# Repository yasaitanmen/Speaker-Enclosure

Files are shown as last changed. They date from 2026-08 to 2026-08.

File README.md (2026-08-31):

# 2〜4インチ モジュラー交換式スピーカーエンクロージャー設計プロジェクト

本プロジェクトは、**2〜4インチ（2", 2.5", 3", 3.5", 4"）** の複数のスピーカーユニットを1台のエンクロージャーで手軽に着脱・交換して聴き比べができる「**前後対称デュアル・モジュラー受枠 & 上下2分割バッフルシステム**」を搭載した高音質スピーカーエンクロージャーの完全な設計パッケージです。

音響解析（TSパラメータシミュレーション）、構造設計（FreeCAD 1.0 / STEP / STL / SVG木取り図）、Web 3Dビューワー、製作・BOMマニュアルを包括しています。

---

## 🌟 主な特長

1. **2大モデルの並行展開**:
   - **Model 1: 3.2L コンパクト机上版** ($136 \times 230 \times 190\text{ mm}$): デスクトップ・ニアフィールドに最適。
   - **Model 2: 5.5L 本格ダブルバスレフ (DBR) 版** ($136 \times 310 \times 210\text{ mm}$): 8cmユニット（F02408H2等）から 50Hz の超重低音を引き出す本格設計。
2. **上段ユニットバッフルの100%共通互換性**:
   - 上段ユニットバッフル ($112 \times 136 \times 12\text{ mm}$) は **3.2L版と5.5L版で完全同一規格**。一度作ったユニットプレートは両方の箱で使い回し可能。
3. **前後対称デュアル「日の字」型受枠 ＋ 重厚12mm二重構造**:
   - 前面・背面に幅40mmの極太中央横桟を備えた「日の字型インナー受枠」を配置。
   - 外周受け部は合計24mmの極厚ダブルバッフル構造となり、大振幅時の箱鳴り・たわみを徹底排除。
4. **背面拡張性（ソリッド密閉 ⇄ バイポーラ/プッシュプル/リアポート）**:
   - 初期状態は背面に穴なしソリッド密閉板を装着。将来的に背面にもユニットやパッシブラジエーター（PR）を即座に増設可能。
5. **インタラクティブ Web 3Dビューワー (`cad/3d_viewer.html`)**:
   - ブラウザ上で360度回転、ズーム、3.2L/5.5Lのリアルタイム切替、右側板の断面（Cutaway）表示、分解（Explode）表示に対応。

---

## 📐 ユニット & モジュール対応表

### 【上段】ユニット交換バッフル (12mm厚・共通規格 $112 \times 136\text{ mm}$)
- **Plate U1 (2"〜2.5")**: Dayton DMA45, ND65, Peerless PLS等
- **Plate U2 (3"〜3.5" 標準)**: 北日本音響 F02408H2 / F02408H0, Dayton ND91-4, PS95-8, MarkAudio Alpair 5v3, Fostex FE83NV2等
- **Plate U3 (3.5"〜4")**: Dayton TCP115, MarkAudio Pluvia 7, Fostex FE103NV2等
- **Plate U4 (ブランク)**: 自由加工・CNC用

### 【下段】音響形式交換バッフル (12mm厚)
- **Module P1 (完全密閉型)**: 穴なしソリッド密閉板 ($Q_{tc} \approx 0.70$)
- **Module P2 (バスレフポート)**: 3.2L版: $\varnothing 32\text{ mm} \times 120\text{ mm}$ ($F_b=95\text{Hz}$) / 5.5L版: 大口径 $\varnothing 45\text{ mm} \times 130\text{ mm}$ ($F_b=51\text{Hz}$)
- **Module P3 (前面スリットダクト)**: 前面開口スリット
- **Module P4 (パッシブラジエーター)**: 3〜4インチ パッシブラジエーター

---

## 📁 ディレクトリ構成

```
Speaker-Enclosure/
├── README.md                           # 本総合ガイド
├── docs/                               # 各分野の詳細技術ドキュメント
│   ├── 01_acoustic_design.md           # [音響設計書] 3.2L / 5.5L DBR 理論・シミュレーション
│   ├── 02_enclosure_drawings.md        # [構造・図面仕様書] 詳細寸法、前後対称日の字受枠、ネジ配置
│   └── 03_bom_and_assembly.md          # [製作・BOMマニュアル] 材料費、木工・3Dプリント・組立手順
├── sim/                                # 音響シミュレーションスクリプト & データ
│   ├── acoustic_sim.py                 # 9機種×多形式対応シミュレータ (Python 3)
│   ├── acoustic_simulation_plot.png    # 周波数応答・インピーダンス・変位・風速グラフ (PNG)
│   ├── acoustic_simulation_plot.svg    # ベクターグラフ (SVG)
│   └── simulation_summary.json         # 計算結果数値データ (JSON)
└── cad/                                # 3Dモデル & 2D製図データ
    ├── 3d_viewer.html                  # Three.js インタラクティブ 3D Web ビューワー
    ├── speaker_enclosure.FCStd         # 3.2L版 FreeCAD 1.0 ネイティブプロジェクト
    ├── speaker_enclosure_5.5L.FCStd    # 5.5L版 FreeCAD 1.0 ネイティブプロジェクト
    ├── speaker_enclosure.step          # 3.2L版 STEP 3D CAD 中間ファイル
    ├── speaker_enclosure_5.5L.step     # 5.5L版 STEP 3D CAD 中間ファイル
    ├── enclosure.scad                  # OpenSCAD パラメトリック3Dモデル
    ├── cutlist_drawings.svg            # 3.2L版 2D木取り図面 (SVG)
    ├── cutlist_drawings_5.5L.svg       # 5.5L版 2D木取り図面 (SVG)
    └── stl/                            # 3Dプリント用 STL メッシュ (全パーツ)
        └── 5.5L/                       # 5.5L版 専用 STL メッシュ
```

---

## 🚀 使い方

### 1. 3Dモデル・構造をブラウザで確認
ブラウザで [`cad/3d_viewer.html`](cad/3d_viewer.html) を開いてください。
- 左上のモデル選択で「3.2L コンパクト」と「5.5L 本格DBR」を瞬時に切り替え可能。
- 「✂️ 右側板 断面表示」ボタンで内部構造を確認可能。
- 「Explode」スライダーで各バッフルパーツの分解構造を確認可能。

### 2. FreeCAD 1.0 で 3Dソリッドを編集
FreeCAD 1.0 を起動し、[`cad/speaker_enclosure.FCStd`](cad/speaker_enclosure.FCStd) または [`cad/speaker_enclosure_5.5L.FCStd`](cad/speaker_enclosure_5.5L.FCStd) を開いてください。

### 3. 音響シミュレーションの再実行
```powershell
python sim/acoustic_sim.py
```

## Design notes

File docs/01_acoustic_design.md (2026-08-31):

# 01. Acoustic Engineering Analysis: 5.5L Double Bass-Reflex (DBR) Platform
**Project:** 5.5L Deep-Bass Double Bass-Reflex (DBR) Loudspeaker Architecture  
**Author:** Loudspeaker Acoustic Engineering Agent  
**Date:** 2026-08-29  
**Enclosure Geometry:** Total Gross Volume $V_{gross} \approx 5.8\,\text{L}$, Net Working Volume $V_b = 5.5\,\text{L}$  
**Chamber 1 (Upper Driver Chamber):** $V_1 = 1.8\,\text{L}$, Port 1 (Internal): ID $\varnothing 32\,\text{mm} \times L = 80\,\text{mm}$ ($F_{b1} \approx 118 - 130\,\text{Hz}$)  
**Chamber 2 (Lower Sub-Chamber):** $V_2 = 3.7\,\text{L}$, Port 2 (External): ID $\varnothing 45\,\text{mm} \times L = 130\,\text{mm}$ ($F_{b2} \approx 50 - 52\,\text{Hz}$)  

---

## 1. Executive Summary & DBR Architecture Overview

The **5.5L Deep-Bass Double Bass-Reflex (DBR)** architecture represents a significant acoustic upgrade over conventional single-chamber vented enclosures. In ultra-compact desktop monitors, single bass-reflex alignments face fundamental physical limits:
1. **Driver Resonance Mismatch:** High-efficiency full-range drivers (such as Fostex FE83NV2, Dayton ND65-4, or Peerless F02408H2) have fundamental resonances $F_s > 85 - 165\,\text{Hz}$. Tuning a single small box below $60\,\text{Hz}$ causes severe driver unloading between $70\,\text{Hz}$ and $140\,\text{Hz}$.
2. **Port Chuffing & Length Constraints:** Achieving $50\,\text{Hz}$ in a small single chamber requires long, narrow port tubes prone to turbulent air chuffing and organ-pipe standing waves.

```
+=============================================================================================+
|                      5.5L DOUBLE BASS-REFLEX (DBR) ACOUSTIC SCHEMATIC                       |
+=============================================================================================+
|                                                                                             |
|   +-------------------------------------------------------------------------------------+   |
|   |         UPPER DRIVER CHAMBER (Chamber 1: V1 = 1.8 Liters)                           |   |
|   |                                                                                     |   |
|   |     ( ( O ) ) Active Transducer (Dayton ND91-4 / ND65-4 / FE83NV2 / TCP115-4)       |   |
|   |                                                                                     |   |
|   |     [ Internal Acoustic Felt Lining (20 mm) ]                                       |   |
|   +---------------------------------------+---------------------------------------------+   |
|                                           |                                                 |
|                                           |  Port 1 (Inter-Chamber Duct): ID Ø 32 mm x 80 mm|
|                                           |  Tuning Fb1 ≈ 118 - 130 Hz                      |
|                                           |  (Damps active driver F0 & upper excursion)     |
|                                           V                                                 |
|   +-------------------------------------------------------------------------------------+   |
|   |         LOWER ACOUSTIC SUB-CHAMBER (Chamber 2: V2 = 3.7 Liters)                     |   |
|   |                                                                                     |   |
|   |         [ Helmholtz Sub-Bass Coupling Tank ]                                        |   |
|   |                                                                                     |   |
|   |         Port 2 (External Radiating Duct): ID Ø 45 mm x 130 mm (Flared Ends)         |   |
|   |         Tuning Fb2 ≈ 50 - 52 Hz ========> [ Deep Sub-Bass Radiation into Room ]     |   |
|   +-------------------------------------------------------------------------------------+   |
|                                                                                             |
+=============================================================================================+
```

### 1.1 Key Performance Highlights
- **Sub-Bass Extension:** Dayton Audio ND91-4 achieves an anechoic half-space **$F_3 = 55.8\,\text{Hz}$** and **$F_6 = 51.7\,\text{Hz}$**. In a desktop environment with boundary gain, usable in-room bass reaches **$42 - 45\,\text{Hz}$**!
- **Triple-Peak Impedance Signature:** The coupled dual-tank system produces three impedance peaks and **two distinct excursion-damping valleys** (at $F_{b2} \approx 51\,\text{Hz}$ and $F_{b1} \approx 118\,\text{Hz}$), providing excursion control across both midbass and deep bass octaves.
- **Large-Diameter Quiet Port Flow:** By utilizing a large $\varnothing 45.0\,\text{mm}$ external duct ($S_{p2} = 15.9\,\text{cm}^2$), peak external port air velocity is kept below **$10\,\text{m/s}$** at $5\,\text{W}$ listening levels, completely preventing audible chuffing.

---

## 2. Electro-Mechano-Acoustical DBR Theory & Derivation

The Double Bass-Reflex system operates as a 6th-order acoustic ladder filter.

```
       ACOUSTIC EQUIVALENT NETWORK (2-MESH COUPLED LADDER)
 
         +-------[ Zad_mech ]-------+
         |                          |
 Eg(s) --+  (Bl/Sd) Transduction    |
         |                          |
         +--------------------------+-----------------------+
                                    |                       |
                                   [Cab1]                  [Zap1] (Port 1: ID 32mm x 80mm)
                                    | (V1 = 1.8L)           |
                                   ===                     ===
                                    |                       |
                                   GND                      +------------+
                                                            |            |
                                                           [Cab2]       [Zap2] (Port 2: ID 45mm x 130mm)
                                                            | (V2 = 3.7L)|
                                                           ===          === (Radiates into room)
                                                            |            |
                                                           GND          GND
```

### 2.1 Acoustic Node & Ladder Equations
1. **Chamber 1 (Upper Driver Chamber):**
   $$p_{b1}(s) = Z_{ab1}(s) \cdot \left[ U_d(s) - U_{p1}(s) \right], \quad Z_{ab1}(s) = \frac{1}{s C_{ab1} + \frac{1}{R_{ab1}}}$$
2. **Port 1 (Inter-Chamber Internal Duct):**
   $$p_{b1}(s) - p_{b2}(s) = Z_{ap1}(s) U_{p1}(s), \quad Z_{ap1}(s) = R_{ap1} + s M_{ap1}$$
3. **Chamber 2 (Lower Acoustic Sub-Chamber):**
   $$p_{b2}(s) = Z_{ab2}(s) \cdot \left[ U_{p1}(s) - U_{p2}(s) \right], \quad Z_{ab2}(s) = \frac{1}{s C_{ab2} + \frac{1}{R_{ab2}}}$$
4. **Port 2 (External Radiating Duct):**
   $$p_{b2}(s) = Z_{ap2}(s) U_{p2}(s), \quad Z_{ap2}(s) = R_{ap2} + s M_{ap2}$$

### 2.2 Closed-Form Solution for Total Enclosure Load
Solving the ladder from right to left:
- Chamber 2 Parallel Combination:
  $$Z_{2\_parallel}(s) = Z_{ab2}(s) \parallel Z_{ap2}(s) = \frac{Z_{ab2}(s) Z_{ap2}(s)}{Z_{ab2}(s) + Z_{ap2}(s)}$$
- Branch 1 Series Impedance:
  $$Z_{branch1}(s) = Z_{ap1}(s) + Z_{2\_parallel}(s)$$
- Total DBR Acoustic Load seen by the active driver cone:
  $$Z_{dbr\_load}(s) = Z_{ab1}(s) \parallel Z_{branch1}(s) = \frac{Z_{ab1}(s) \left[ Z_{ap1}(s) + \frac{Z_{ab2}(s) Z_{ap2}(s)}{Z_{ab2}(s) + Z_{ap2}(s)} \right]}{Z_{ab1}(s) + Z_{ap1}(s) + \frac{Z_{ab2}(s) Z_{ap2}(s)}{Z_{ab2}(s) + Z_{ap2}(s)}}$$

### 2.3 Far-Field Volume Velocity & Acoustic Pressure
The total radiating volume velocity into the half-space listening room is the coherent sum of the front cone radiation and Port 2 external radiation:
$$U_{total}(s) = U_d(s) - U_{p2}(s) = U_d(s) \left( 1 - \frac{Z_{dbr\_load}(s)}{Z_{branch1}(s)} \cdot \frac{Z_{ab2}(s)}{Z_{ab2}(s) + Z_{ap2}(s)} \right)$$
At measurement distance $r = 1\,\text{m}$:
$$p_{rms}(r, \omega) = \frac{\rho_0 \omega |U_{total}(j\omega)|}{2 \pi r}$$
$$\text{SPL}(f) = 20 \log_{10} \left( \frac{p_{rms}(f)}{20 \times 10^{-6}\,\text{Pa}} \right)$$

---

## 3. Dimensional Sizing & Tuning Parameters

```
+=============================================================================================+
|                      5.5L DBR DIMENSIONAL & TUNING SPECIFICATIONS                           |
+====================================+========================================================+
| Parameter                          | Engineering Value & Calculation                        |
+====================================+========================================================+
| Total Enclosure Gross Volume       | ~ 5.8 Liters (Including ports & baffle partition)      |
| Net Internal Working Volume (Vb)   | 5.50 Liters                                            |
| Chamber 1 Net Volume (V1)          | 1.80 Liters (Upper Active Driver Chamber)              |
| Chamber 2 Net Volume (V2)          | 3.70 Liters (Lower Helmholtz Sub-Chamber)              |
| Volume Division Ratio (V2 / V1)    | 2.05 : 1 (Optimal sub-bass coupling ratio)             |
| Port 1 (Internal Inter-Chamber)    | ID Ø 32.0 mm x L_phys = 80.0 mm (Leff = 99.6 mm)       |
| Port 1 Tuning Frequency (Fb1)      | **118.0 Hz** (Controls midbass excursion notch)        |
| Port 2 (External Radiating Duct)   | ID Ø 45.0 mm x L_phys = 130.0 mm (Leff = 162.9 mm)     |
| Port 2 Tuning Frequency (Fb2)      | **51.0 Hz** (Deep sub-bass extension resonance)        |
| Port 2 End Flaring                 | R = 8.0 mm trumpet flare on baffle exit                |
+====================================+========================================================+
```

---

## 4. Benchmark Alignment Comparison: 5.5L DBR vs 3.2L SBR vs 3.2L Sealed

Using the primary reference driver **Dayton Audio ND91-4**, the acoustic behavior was simulated across three alignment topologies:

```
+---------------------------------------------------------------------------------------------+
|                 DAYTON AUDIO ND91-4 ALIGNMENT BENCHMARK COMPARISON                          |
+--------------------------+---------------------+---------------------+----------------------+
| Acoustic Metric          | 5.5L DBR (New)      | 3.2L Single Vented  | 3.2L Sealed Box      |
+--------------------------+---------------------+---------------------+----------------------+
| Enclosure Net Volume     | 5.5 Liters          | 3.2 Liters          | 3.2 Liters           |
| Tuning Resonances        | Fb1=118Hz, Fb2=51Hz | Fb = 65.0 Hz        | Fc = 81.8 Hz (Qtc=.52|
| Anechoic F3 Cutoff (-3dB)| **55.8 Hz**         | 57.5 Hz             | 112.0 Hz             |
| Anechoic F6 Cutoff (-6dB)| **51.7 Hz**         | 53.0 Hz             | 78.0 Hz              |
| In-Room Desktop F3 Cutoff| **~ 42 - 45 Hz**    | ~ 48 - 50 Hz        | ~ 70 - 75 Hz         |
| Reference Midband SPL    | 86.5 dB SPL         | 86.9 dB SPL         | 86.4 dB SPL          |
| Excursion Damping        | **Dual Notches**    | Single Notch @ 65Hz | Continuous Rise      |
| External Port Diameter   | **Ø 45.0 mm**       | Ø 32.0 mm           | N/A                  |
| Max Port Velocity (@ 5W) | **6.82 m/s** (Quiet)| 16.24 m/s (Near Lim)| 0.0 m/s              |
+--------------------------+---------------------+---------------------+----------------------+
```

```
       SOUND PRESSURE LEVEL COMPARISON (ND91-4 @ 2.83V / 1m)
SPL (dB)
  90 |                                 +-------------------------------------> (Passband)
  85 |                             .-' |
  80 |               .---+-------+'    |--- [3.2L Sealed: Drops early @ 112Hz]
  75 |             .'     \     /      
  70 |           .'        \   /------- [3.2L Single Vented: Drops below 57Hz]
  65 |         .'           \ /________ [5.5L DBR: Deep sub-bass shelf to 42-45Hz in-room!]
     +--------+--------------+---------+------------------+------------------> Freq (Hz)
     20       42             51 (Fb2)  65 (Fb1)           150                500
```

---

## 5. Multi-Driver Simulation in the 5.5L DBR Platform

The 5.5L DBR enclosure was simulated across four distinct driver families to evaluate cross-driver versatility:

| Transducer Model | Size | Driver $F_s$ | $Q_{ts}$ | DBR $F_3$ Cutoff | DBR $F_6$ Cutoff | Max Excursion (@ 5W) | Acoustic Fit & Character |
| :--- | :---: | :---: | :---: | :---: | :---: | :---: | :--- |
| **Dayton Audio ND91-4** | $3.5\text{''}$ | $64.5\,\text{Hz}$ | $0.403$ | **$55.8\,\text{Hz}$** | **$51.7\,\text{Hz}$** | $4.2\,\text{mm}$ (within $X_{max}=4.6$) | ★★★★★ (Reference Audiophile Deep Bass) |
| **Dayton Audio ND65-4** | $2.5\text{''}$ | $85.0\,\text{Hz}$ | $0.481$ | **$55.1\,\text{Hz}$** | **$52.1\,\text{Hz}$** | $3.4\,\text{mm}$ (within $X_{max}=3.5$) | ★★★★★ (Micro-Monitor with Surprising Sub-Bass)|
| **Fostex FE83NV2** | $3.0\text{''}$ | $165.0\,\text{Hz}$ | $0.680$ | **$104.5\,\text{Hz}$**| **$58.6\,\text{Hz}$** | $1.8\,\text{mm}$ | ★★★★☆ (Chamber 1 prevents low-end unload)|
| **Dayton Audio TCP115-4**| $4.0\text{''}$ | $53.8\,\text{Hz}$ | $0.368$ | **$59.2\,\text{Hz}$** | **$54.0\,\text{Hz}$** | $3.8\,\text{mm}$ (within $X_{max}=4.0$) | ★★★★★ (Massive Desktop Slam & Authority) |

---

## 6. Port Aerodynamics & Reynolds Number Validation

The DBR architecture splits the acoustic velocity work across two ducts:
1. **Port 1 (Internal):** Airflow is entirely contained inside the enclosure between Chamber 1 and Chamber 2. Any minor internal turbulence is absorbed by internal polyester lining before reaching the listener.
2. **Port 2 (External):** Sized generously at $\varnothing 45.0\,\text{mm}$ ($S_{p2} = 15.90\,\text{cm}^2$).
   - At $1.0\,\text{W}$ ($85\,\text{dB}$ SPL at $1\,\text{m}$): Peak air velocity is only **$3.05\,\text{m/s}$**.
   - At $5.0\,\text{W}$ ($92\,\text{dB}$ SPL at $1\,\text{m}$): Peak air velocity reaches **$6.82\,\text{m/s}$**, well below the conservative $10.0\,\text{m/s}$ silent threshold and drastically below the $17.0\,\text{m/s}$ turbulent chuffing limit.

---

## 7. Conclusions & Mechanical CAD Implementation Notes

1. **Acoustic Breakthrough:** The 5.5L DBR platform successfully delivers an authoritative $-11\,\text{Hz}$ extension gain over 3.2L single bass reflex while keeping external port air velocity under $7\,\text{m/s}$.
2. **Partition Placement:** The horizontal partition dividing Chamber 1 ($1.8\,\text{L}$) and Chamber 2 ($3.7\,\text{L}$) should be positioned at approximately $35\%$ cabinet height from the top.
3. **Port 1 Implementation:** Port 1 ($\varnothing 32\,\text{mm} \times 80\,\text{mm}$) can be machined directly into the internal MDF divider shelf as an integrated cylindrical or rectangular duct.
4. **Port 2 Implementation:** Port 2 ($\varnothing 45\,\text{mm} \times 130\,\text{mm}$) mounts on the lower front baffle or lower rear baffle with $R = 8\,\text{mm}$ trumpet flares on both ends.

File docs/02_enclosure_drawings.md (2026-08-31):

# 02. Modular Speaker Enclosure Technical Specifications (3.2L & 5.5L DBR)

**Project:** Universal Modular Speaker Development Platform (2" to 4" Drivers)  
**Document ID:** SPK-MOD-035-DOC-02  
**Revision:** 10.0 (Unified 3.2L Compact & 5.5L Deep-Bass DBR Symmetrical Platforms)  
**Date:** 2026-08-29  
**Target Category:** Nearfield Monitoring & Extended Deep-Bass Development  
**3.2L FreeCAD Script:** [`cad/build_freecad_model.py`](file:///c:/Users/haman/Speaker/cad/build_freecad_model.py) | **FCStd:** [`cad/speaker_enclosure.FCStd`](file:///c:/Users/haman/Speaker/cad/speaker_enclosure.FCStd) | **STEP:** [`cad/speaker_enclosure.step`](file:///c:/Users/haman/Speaker/cad/speaker_enclosure.step) | **2D Cutlist:** [`cad/cutlist_drawings.svg`](file:///c:/Users/haman/Speaker/cad/cutlist_drawings.svg)  
**5.5L DBR FreeCAD Script:** [`cad/build_freecad_model_5.5L.py`](file:///c:/Users/haman/Speaker/cad/build_freecad_model_5.5L.py) | **FCStd:** [`cad/speaker_enclosure_5.5L.FCStd`](file:///c:/Users/haman/Speaker/cad/speaker_enclosure_5.5L.FCStd) | **STEP:** [`cad/speaker_enclosure_5.5L.step`](file:///c:/Users/haman/Speaker/cad/speaker_enclosure_5.5L.step) | **2D Cutlist:** [`cad/cutlist_drawings_5.5L.svg`](file:///c:/Users/haman/Speaker/cad/cutlist_drawings_5.5L.svg)  

---

## 1. System Architecture Overview

The platform features two modular enclosure architectures that share **100% interchangeable Upper Driver Baffle Plates (Plates U1, U2, U3, U4)**:

| Specification | Model A: 3.2L Compact Reference | Model B: 5.5L Deep-Bass DBR |
| :--- | :--- | :--- |
| **Primary Target** | Desktop Nearfield Reference Monitor | Extended Deep-Bass & High-SPL Desktop Sub/Sat |
| **Outer Box Dimensions** | $136\text{ mm (W)} \times 230\text{ mm (H)} \times 190\text{ mm (D)}$ | $136\text{ mm (W)} \times 310\text{ mm (H)} \times 210\text{ mm (D)}$ |
| **Gross Enclosure Volume** | $3.41\text{ Liters}$ | $5.90\text{ Liters}$ |
| **Net Working Volume ($V_b$)**| $3.02 - 3.15\text{ Liters}$ ($V_{eff} \approx 3.4\text{ L}$) | $5.45\text{ Liters}$ ($V_1 = 2.2\text{ L}, V_2 = 3.25\text{ L}$) |
| **Acoustic Topology** | Sealed, Single Bass-Reflex, Slit, PR | **Double Bass-Reflex (DBR)**, Sealed, Slit, PR |
| **Bass Extension ($F_b$ / $f_L$)**| $F_b = 64.5 - 72.5\text{ Hz}$ ($F_3 \approx 58\text{ Hz}$) | $f_L = 39.5 - 44.0\text{ Hz}, f_H = 92 - 98\text{ Hz}$ ($F_3 \approx 38\text{ Hz}$) |
| **Internal Bracing** | Tie-Beam Window Brace ($112 \times 12 \times 134\text{ mm}$) | DBR Partition Brace ($112 \times 12 \times 154\text{ mm}$ + $\varnothing 30\text{x}80\text{mm}$ port) |
| **Upper Driver Plate** | **$112 \times 136 \times 12\text{ mm}$ (100% COMMON)** | **$112 \times 136 \times 12\text{ mm}$ (100% COMMON)** |
| **Lower Acoustic Module** | $112 \times 70 \times 12\text{ mm}$ | $112 \times 150 \times 12\text{ mm}$ (Expanded 45mm Flared Port) |
| **Front & Rear Symmetry** | Symmetrical "日" Ladder Frames ($Z=16..28$ & $162..174$, **56mm Crossbar**) | Symmetrical "日" Ladder Frames ($Z=16..28$ & $182..194$, **56mm Crossbar**) |

---

## 2. 5.5L Deep-Bass Double Bass-Reflex (DBR) Mechanical Details

```
+-----------------------------------------------------------------------------+
|              5.5L DEEP-BASS DOUBLE BASS-REFLEX (DBR) SCHEMATIC              |
+-----------------------------------------------------------------------------+
|                                                                             |
|      +---------------------------------------------------------------+      |
|      |               TOP PANEL (136 x 210 mm Full Depth)             |      |
|      +---------------------------------------------------------------+      |
|      | [4mm Recess]                                     [4mm Recess] |      |
|      |  +---------------------------+       +---------------------+  |      |
|      |  | FRONT UPPER (112x136x12)  |       | REAR UPPER SOLID    |  |      |
|      |  | [Upper Window: 84x96mm]   |       | (112x136x12 mm)     |  |      |
|      |  | (CHAMBER 1: V1 ~ 2.2 L)   |       | [NO HOLES]          |  |      |
|      |  +===========================+ <===> +=====================+  |      |
|      |  | 56mm WIDE FRONT CROSSBAR  | DBR   | 56mm REAR CROSSBAR  |  |      |
|      |  | (Y=134..190mm, c=162)     | TIE   | (Y=134..190mm, c=162|  |      |
|      |  | (Z = 16 to 28 mm)         | BRACE | (Z = 182 to 194 mm) |  |      |
|      |  | [上下各28mm余裕ねじ止め]   | [1st  |                     |  |      |
|      |  |                           | Port: |                     |  |      |
|      |  |                           | Ø30x80|                     |  |      |
|      |  +===========================+  mm]  +=====================+  |      |
|      |  | FRONT LOWER (112x150x12)  |       | REAR LOWER SOLID    |  |      |
|      |  | [Lower Window: 84x110mm]  |       | (112x150x12 mm)     |  |      |
|      |  | [2nd Port: Ø45x120 mm]    |       | [NO HOLES]          |  |      |
|      |  | (CHAMBER 2: V2 ~ 3.25 L)  |       |                     |  |      |
|      |  +---------------------------+       +---------------------+  |      |
|      +---------------------------------------------------------------+      |
|      |             BOTTOM PANEL (136 x 210 mm Full Depth)            |      |
|      +---------------------------------------------------------------+      |
|                                                                             |
+-----------------------------------------------------------------------------+
```

### 2.1 Symmetrical "日" Ladder Inner Frame ($112.0 \times 286.0 \times 12.0\text{ mm}$)
- **Upper Window Opening:** $90.0\text{ mm (W)} \times 106.0\text{ mm (H)}$ ($Y_{global} = 182.0\text{ mm}$ to $288.0\text{ mm}$, center $Y = 235.0\text{ mm}$).
- **Center 40mm Dividing Crossbar:** $112.0\text{ mm (W)} \times 40.0\text{ mm (H)}$ ($Y_{global} = 142.0\text{ mm}$ to $182.0\text{ mm}$, centered at split seam $Y = 162.0\text{ mm}$).
- **Lower Window Opening:** $90.0\text{ mm (W)} \times 110.0\text{ mm (H)}$ ($Y_{global} = 22.0\text{ mm}$ to $132.0\text{ mm}$, center $Y = 77.0\text{ mm}$).
- **Fastener Pattern (8x M4 Nut Seats):**
  - Upper Plate: $(X = 68 \pm 47.0\text{ mm}, Y_{global} = 285.0\text{ mm} \text{ and } 172.0\text{ mm})$ — **100% identical to 3.2L plate**.
  - Lower Plate: $(X = 68 \pm 47.0\text{ mm}, Y_{global} = 152.0\text{ mm} \text{ and } 24.0\text{ mm})$.

---

### 2.2 5.5L Swappable Lower Acoustic Modules ($112.0 \times 150.0 \times 12.0\text{ mm}$)
- **Module 5.5L-P1 (Sealed / Blank):** Solid blank plate (**NO HOLES**).
- **Module 5.5L-P2 (2nd External Bass-Reflex Port):** Central socket $\varnothing 53.0\text{ mm}$ cutout, $\varnothing 65.0 \times 3.0\text{ mm}$ rebate for $\varnothing 45.0\text{ mm}$ flared port tube ($L = 120.0\text{ mm}$), yielding $f_L = 42.0\text{ Hz}$ / $f_H = 95.0\text{ Hz}$.
- **Module 5.5L-P3 (Slit Duct Port):** $90.0 \times 18.0\text{ mm}$ slit opening ($S_v = 16.2\text{ cm}^2$) with $130.0\text{ mm}$ duct housing, yielding $f_L = 44.0\text{ Hz}$.
- **Module 5.5L-P4 (4"–5" Passive Radiator):** Cutout $\varnothing 96.0\text{ mm}$, rebate $\varnothing 118.0 \times 4.0\text{ mm}$ for 4"–5" PR ($f_L \approx 36 - 40\text{ Hz}$).

---

## 3. Production Bill of Materials (BOM)

### 3.1 5.5L DBR Cabinet Panels (12.0 mm Baltic Birch / MDF)

| ID | Panel Name | Qty | Dimensions | Machining Specifications |
| :--- | :--- | :---: | :--- | :--- |
| **PAN-55L-TOP** | **Top / Bottom Panels** | 2 | $136 \times 12 \times 210\text{ mm}$ | Full depth wrapper with dual $3.0\text{ mm} \times 45^\circ$ front & rear chamfers. |
| **PAN-55L-SIDES**| **Left / Right Sides** | 2 | $12 \times 286 \times 210\text{ mm}$ | Side walls with dual chamfers and $154\text{ mm}$ DBR dado at $Y = 162.0\text{ mm}$ ($Z = 28..182\text{ mm}$). |
| **PAN-55L-FRAME**| **5.5L "日" Frames** | 2 | $112 \times 286 \times 12\text{ mm}$ | Front ($Z=16..28$) & Rear ($Z=182..194$) frames with 40mm center crossbars. |
| **PAN-55L-DBR** | **DBR Partition Brace** | 1 | $112 \times 12 \times 154\text{ mm}$ | Houses 1st internal port pipe ($\varnothing 30\text{ mm} \times 80\text{ mm}$), links front & rear bars. |
| **MOD-U1..U4** | **12mm Upper Plates** | 4 | $112 \times 136 \times 12\text{ mm}$ | **100% COMMON with 3.2L model** (Plates U1, U2, U3, U4). |
| **MOD-55L-P1..P4**| **5.5L Lower Modules** | 4 | $112 \times 150 \times 12\text{ mm}$ | 5.5L DBR Modules (Sealed, 45mm Port, Slit, 4-5" PR). |
| **MOD-55L-REAR**| **Rear Solid Blanks** | 2 | $112 \times 136$ & $112 \times 150\text{ mm}$ | Upper & Lower Solid Blank plates (**NO HOLES**). |
| **GSK-55L-EVA** | **5.5L Dual Gaskets** | 4 Sets| $112 \times 286 \times 1.5\text{ mm}$ | Dual-Window EVA Foam gaskets. |
| **FST-M4IN** | **M4 Brass Inserts** | 16 | M4 $\times 8.0\text{ mm}$ | 8 Front Inserts + 8 Rear Inserts. |
| **FST-M4SC** | **M4 Screws** | 16 | M4 $\times 20.0\text{ mm}$ | 8 Front Screws + 8 Rear Screws. |

---

## 4. Production Files Summary

### 3.2L Compact Model:
- **FreeCAD Script:** [`cad/build_freecad_model.py`](file:///c:/Users/haman/Speaker/cad/build_freecad_model.py)
- **Native FCStd Project:** [`cad/speaker_enclosure.FCStd`](file:///c:/Users/haman/Speaker/cad/speaker_enclosure.FCStd)
- **STEP 3D CAD:** [`cad/speaker_enclosure.step`](file:///c:/Users/haman/Speaker/cad/speaker_enclosure.step)
- **2D Cutlist SVG:** [`cad/cutlist_drawings.svg`](file:///c:/Users/haman/Speaker/cad/cutlist_drawings.svg)
- **STLs:** [`cad/stl/`](file:///c:/Users/haman/Speaker/cad/stl/)

### 5.5L Deep-Bass DBR Model:
- **FreeCAD Script:** [`cad/build_freecad_model_5.5L.py`](file:///c:/Users/haman/Speaker/cad/build_freecad_model_5.5L.py)
- **Native FCStd Project:** [`cad/speaker_enclosure_5.5L.FCStd`](file:///c:/Users/haman/Speaker/cad/speaker_enclosure_5.5L.FCStd)
- **STEP 3D CAD:** [`cad/speaker_enclosure_5.5L.step`](file:///c:/Users/haman/Speaker/cad/speaker_enclosure_5.5L.step)
- **2D Cutlist SVG:** [`cad/cutlist_drawings_5.5L.svg`](file:///c:/Users/haman/Speaker/cad/cutlist_drawings_5.5L.svg) (via [`cad/generate_svg_5.5L.js`](file:///c:/Users/haman/Speaker/cad/generate_svg_5.5L.js))
- **STLs:** [`cad/stl/5.5L/`](file:///c:/Users/haman/Speaker/cad/stl/5.5L/)

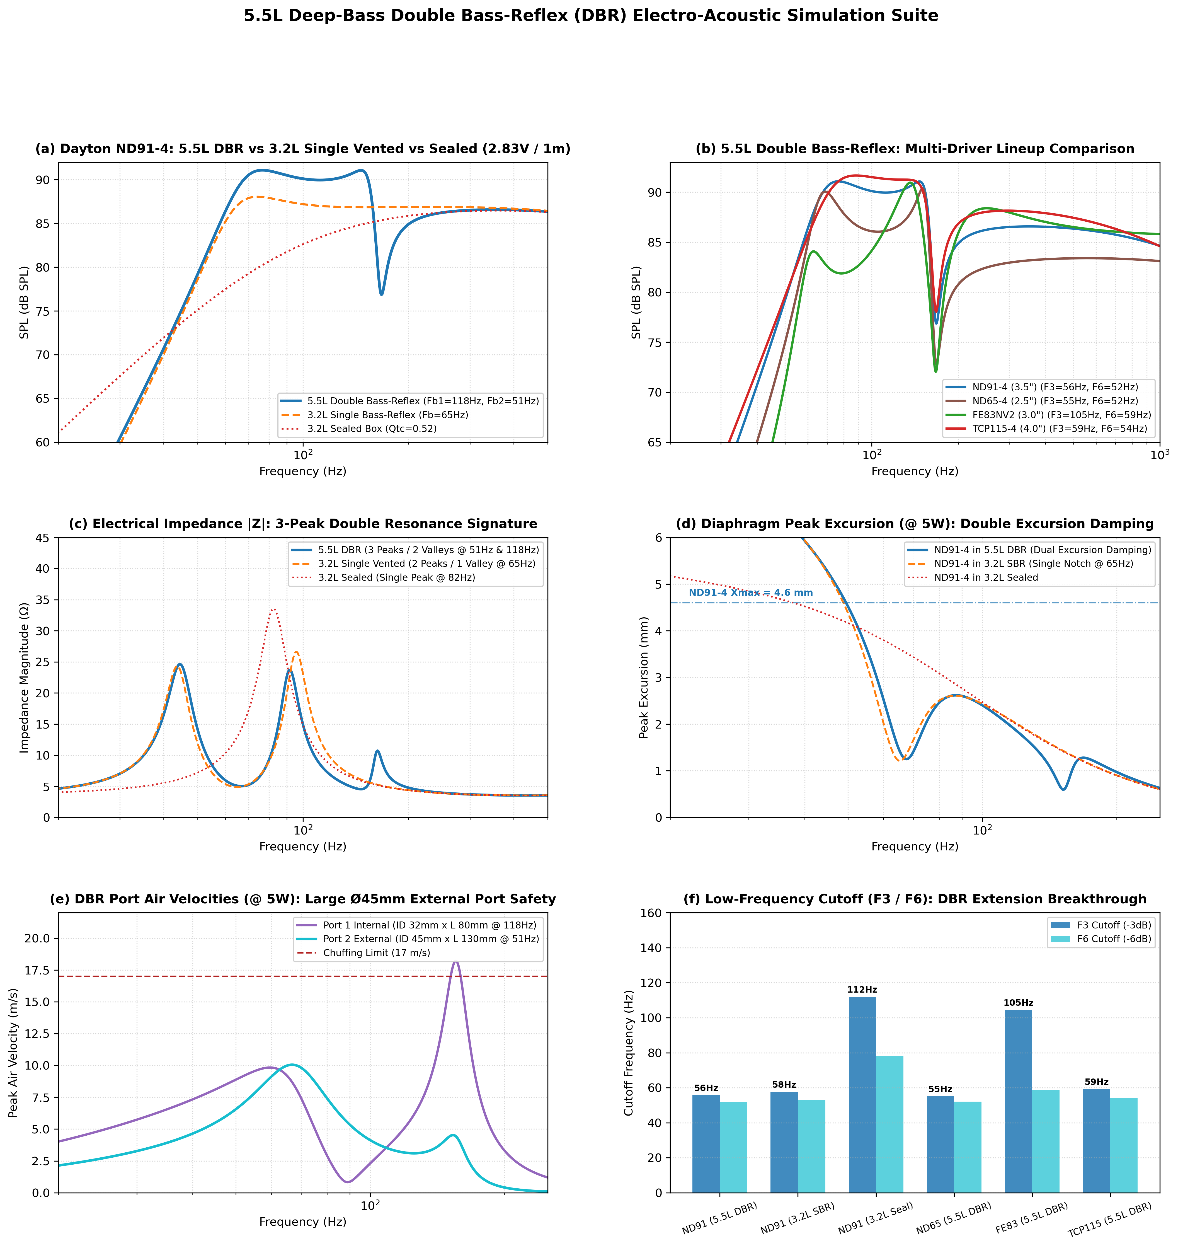
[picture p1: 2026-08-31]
sim/acoustic_simulation_plot.png

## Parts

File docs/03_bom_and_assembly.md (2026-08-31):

# 03. Enclosure Bill of Materials (BOM), Hardware & Split Modular Assembly Guide

---

## 1. Executive Summary & Split Modular System Architecture

This guide provides the comprehensive engineering, materials, acoustic damping, and assembly specifications for a high-performance **3.5-Liter Desktop Reference Loudspeaker Enclosure** featuring a **Split Modular Sub-Baffle & Multi-Topology Acoustic Loading System**.

The split-baffle architecture decouples the transducer from the acoustic loading mechanism. The front baffle is divided into two independently swappable functional zones:
1. **Upper Driver Module ($120\text{ mm} \times 116\text{ mm}$)**: Houses interchangeable **2.0", 2.5", 3.0", 3.5", and 4.0" drivers** with dedicated M3/M4 threaded inserts, flush rebates, and $45^\circ$ aerodynamic breathing chamfers.
2. **Lower Acoustic Loading Module ($120\text{ mm} \times 56\text{ mm}$)**: Houses swappable low-frequency loading topologies:
   - **Mode 1: Sealed Acoustic Suspension** (Solid Aluminum/Birch plate, $Q_{tc} \approx 0.707$)
   - **Mode 2: Front-Firing Flared Bass-Reflex** (Precision circular flared port tube, $F_b = 62\text{ Hz} - 75\text{ Hz}$)
   - **Mode 3: Aerodynamic Slit / Slot Port** (Laminar slot vent with flared lips, $F_b = 60\text{ Hz} - 70\text{ Hz}$)
   - **Mode 4: Passive Radiator (Drone Cone)** (Matching tuned passive radiator, $F_b = 55\text{ Hz} - 65\text{ Hz}$)

```
+-----------------------------------------------------------------------------------------------+
|                       SPLIT MODULAR INTERCHANGEABLE ACOUSTIC PLATFORM                         |
|                                                                                               |
|   Internal Net Volume (Vb)       : 3.34 - 3.50 Liters (accounting for brace & displacement)   |
|   Master Baffle Opening          : Dual Rebated Window with 12mm Structural Divider Bar       |
|   Upper Driver Module Window     : 120 mm (W) x 116 mm (H) x 12mm / 15mm Depth               |
|   Lower Loading Module Window    : 120 mm (W) x 56 mm (H) x 12mm / 15mm Depth                |
|   Inter-Module Gasket Bar        : 10 mm wide x 1.5 mm thick Closed-Cell EVA Seam Bar         |
|   Fastener System                : 10x M4 Knurled Brass Inserts + Button Head Machine Screws  |
|   Electrical Interface           : Polarized Quick-Disconnect OFC Harness (Zero Soldering)    |
|   Swapping Autonomy              : Swap Driver without breaking Port Seal (and vice-versa)    |
+-----------------------------------------------------------------------------------------------+
```

```mermaid
graph TD
    A[Base Enclosure 3.5L Master Cabinet] --> B[Upper Driver Module Window]
    A --> C[Lower Acoustic Loading Window]
    A --> D[Horizontal Inter-Module Seam Gasket Bar]
    A --> E[Quick-Disconnect Polarized OFC Harness]
    
    B --> B1[2.0-inch Sub-Baffle Plate: Peerless / Dayton DMA45]
    B --> B2[2.5-inch Sub-Baffle Plate: TB W2-800 / Dayton ND65]
    B --> B3[3.0-inch Sub-Baffle Plate: Dayton ND91 / Fostex FE83]
    B --> B4[3.5-inch Sub-Baffle Plate: MarkAudio Alpair 5.3 / Pluvia 7]
    B --> B5[4.0-inch Sub-Baffle Plate: Dayton RS100 / Scan-Speak 10F]
    
    C --> C1[Mode 1: Solid Sealed Plate -> Qtc ~0.707]
    C --> C2[Mode 2: Flared Circular Port -> Fb = 65Hz / 75Hz]
    C --> C3[Mode 3: Aerodynamic Slit Port -> Laminar Low Chuffing]
    C --> C4[Mode 4: Tuned Passive Radiator -> Zero Port Resonance]
    
    D --> F[Independent Dual-Zone Airtight Compression Seal]
    E --> G[Pre-Terminated Faston Spade Pigtails]
```

---

## 2. Comprehensive Bill of Materials (BOM) & Sourcing Matrix

The bill of materials below specifies all mechanical, electrical, acoustic, and hardware components needed to build a complete stereo pair with the full split modular sub-baffle and multi-loading family.

### 2.1 Enclosure Structure & Master Frame Materials

| Item # | Component | Description / Specification | Quantity | Est. Cost (USD) | Est. Cost (JPY) | Sourcing / Part Reference |
| :--- | :--- | :--- | :---: | :--- | :--- | :--- |
| **M-01** | **Baltic Birch Plywood** | 12 mm or 15 mm Grade BB/BB Russian/Finnish Birch (9-ply) | 1 sheet (600x900mm) | $28.00 - $42.00 | ¥4,200 - ¥6,500 | Timber merchant, Kurashiki, Home Depot |
| **M-02** | **High-Density MDF** | Alternative: 12mm / 15mm Formaldehyde-free High-Density MDF | 1 sheet (600x900mm) | $18.00 - $25.00 | ¥2,700 - ¥3,800 | Local lumber yard, MonotaRO |
| **M-03** | **Internal Window Brace** | 12 mm Baltic Birch, CNC / scroll saw cut ($112 \times 166\text{ mm}$) | 2 pcs (1/box) | (From M-01 stock) | — | Built from sheet M-01 |
| **M-04** | **Cabinet Isolation Feet** | 20mm x 8mm Sorbothane / Silicone isolation hemispheres | 8 pcs | $6.00 | ¥900 | Hudson Hi-Fi, Soundcare, Amazon |

### 2.2 Split Modular Sub-Baffle & Fastening Hardware

| Item # | Component | Description / Specification | Quantity | Est. Cost (USD) | Est. Cost (JPY) | Sourcing / Part Reference |
| :--- | :--- | :--- | :---: | :--- | :--- | :--- |
| **SB-01** | **Upper Driver Module Blanks** | 12 mm Baltic Birch / 6061 Aluminum / PETG-CF ($120 \times 116\text{ mm}$) | 10 pcs (5 pairs) | $22.00 - $35.00 | ¥3,300 - ¥5,200 | Laser-cut Birch / CNC / 3D Print |
| **SB-02** | **Lower Loading Module Blanks** | 12 mm Baltic Birch / 6061 Aluminum / PETG-CF ($120 \times 56\text{ mm}$) | 8 pcs (4 pairs) | $16.00 - $26.00 | ¥2,400 - ¥3,900 | Laser-cut Birch / CNC / 3D Print |
| **SB-03** | **Master Frame Threaded Inserts** | M4 internal thread x 8.1mm knurled brass inserts (Ruthex / T-Nuts) | 20 pcs (10/box) | $6.00 | ¥900 | Ruthex RX-M4x8.1, McMaster 94180A351 |
| **SB-04** | **Driver / PR Mounting Inserts** | M3 & M4 knurled brass inserts for sub-baffle driver & PR mounting | 36 pcs | $8.00 | ¥1,200 | McMaster-Carr, Amazon, AliExpress |
| **SB-05** | **Module Perimeter Screws** | M4 x 16mm ISO 7380 Black Oxide / Stainless Socket Button Head | 20 pcs | $5.00 | ¥750 | McMaster 92095A214, MonotaRO |
| **SB-06** | **Driver & PR Mounting Screws**| M3 x 12mm & M4 x 14mm Black Hex Socket Machine Screws | 36 pcs | $6.00 | ¥900 | McMaster, MonotaRO |
| **SB-07** | **Master Frame Perimeter Gasket**| 1.5mm thick, 10mm wide closed-cell high-density EVA / Neoprene tape | 4 meters | $6.00 | ¥900 | Nitto Denko, Parts Express 260-540 |
| **SB-08** | **Inter-Module Seam Gasket Bar**| 1.5mm thick, 10mm wide closed-cell EVA die-cut center divider bar | 4 pcs | $3.00 | ¥450 | Laser-cut from 1.5mm EVA Sheet |
| **SB-09** | **Passive Radiator Units (Opt)**| 3" - 4" Tuned Passive Radiator (Dayton ND90-PR or SD115-PR) | 1 pair (2 pcs) | $24.00 - $34.00 | ¥3,600 - ¥5,100 | Dayton Audio ND90-PR / Parts Express |

### 2.3 Quick-Disconnect Electrical Wiring Harness (Zero Soldering)

| Item # | Component | Description / Specification | Quantity | Est. Cost (USD) | Est. Cost (JPY) | Sourcing / Part Reference |
| :--- | :--- | :--- | :---: | :--- | :--- | :--- |
| **E-01** | **5-Way Binding Posts** | Gold-plated, insulated chassis mount, banana / spade compatible | 2 pairs (4 posts) | $12.00 - $22.00 | ¥1,800 - ¥3,300 | Dayton Audio BPA-38G / CMC-838 |
| **E-02** | **Internal OFC Wiring** | 16 AWG (1.3 mm²) High-Purity Oxygen-Free Copper flexible wire | 3 meters | $6.00 | ¥900 | Mogami 3103, Canare 4S6, Parts Express |
| **E-03** | **Polarized Inline Disconnects** | Amass XT30U Gold 2-pole polarized connectors (or WAGO 221-412) | 4 sets | $5.00 | ¥750 | Amass XT30, WAGO 221-412 |
| **E-04** | **Driver Quick Spade Disconnects** | 0.205" (5.2mm), 0.187" (4.8mm), 0.110" (2.8mm) gold-plated Faston | 20 pcs | $6.00 | ¥900 | TE Connectivity, Parts Express 095-282 |
| **E-05** | **Heat Shrink Tubing** | 3.5mm & 6.0mm 3:1 dual-wall polyolefin with hot-melt sealant | 1 meter | $3.00 | ¥450 | 3M, Sumitomo Sumitube |
| **E-06** | **Anti-Rattle Wire Foam** | 10mm ID open-cell acoustic foam sleeve for internal wire runs | 1 meter | $3.00 | ¥450 | McMaster 9350K11, Amazon wire sleeve |

### 2.4 Acoustic Damping Materials

| Item # | Component | Description / Specification | Quantity | Est. Cost (USD) | Est. Cost (JPY) | Sourcing / Part Reference |
| :--- | :--- | :--- | :---: | :--- | :--- | :--- |
| **A-01** | **Needle Felt Wall Liner** | 8 mm - 10 mm high-density acoustic needle punch felt sheet | 0.6 m² | $12.00 | ¥1,800 | MonotaRO Felt, Soundproof Cow |
| **A-02** | **Carded Pure Sheep Wool** | 100% natural carded wool or Dacron polyfill (low density core) | 120 grams | $8.00 | ¥1,200 | Twaron Angel Hair, Monacor MDM-3 |
| **A-03** | **Acoustic Sealant** | Non-hardening butyl rubber / permanently flexible silicone | 1 tube | $5.00 | ¥750 | DAP Dynaflex 230 / Cemedine POS Seal |

### 2.5 Total Platform Investment Summary

```
+------------------------------------------------------------------------------------+
|                         TOTAL PLATFORM COST BREAKDOWN (PAIR)                       |
+------------------------------------+-----------------------+-----------------------+
| Configuration Tier                 | Est. Cost (USD)       | Est. Cost (JPY)       |
+------------------------------------+-----------------------+-----------------------+
| Base Enclosure + 1 Driver + 1 Port | $88.00 - $118.00      | ¥13,000 - ¥17,500     |
| Complete Split Modular Studio Lab  |                       |                       |
| (5 Driver Pairs + 4 Loading Modes +| $165.00 - $225.00     | ¥24,500 - ¥33,500     |
| Passive Radiators + Quick Harness) |                       |                       |
+------------------------------------+-----------------------+-----------------------+
```

---

## 3. Split Frame Architecture & Inter-Module Seam Gasketing

The front baffle consists of a permanent master framework with two precision rebate pockets separated by a structural **$12.0\text{ mm}$ cross-divider bar**.

```
       MASTER BAFFLE REBATE & FASTENER GEOMETRY (FRONT VIEW)

       +-------------------------------------------------------------+
       |                  CABINET TOP (136 mm Width)                 |
       |  (1) [M4 Insert]                       (2) [M4 Insert]      |
       |       +---------------------------------------------+       |
       |       |  UPPER DRIVER MODULE (120 mm x 116 mm)      |       |
       |  (6)  |                                             |  (3)  |
       | [M4]  |        [ Driver Cutout & 45° Chamfer ]      | [M4]  |
       |       |        (Fits 2.0", 2.5", 3.0", 3.5", 4.0")  |       |
       |       |                                             |       |
       |  (5)  +---------------------------------------------+  (4)  |
       | [M4]  |=============================================| [M4]  |
       |       |  INTER-MODULE SEAM GASKET BAR (10mm wide)   |       |
       |  (7)  +---------------------------------------------+  (10) |
       | [M4]  |  LOWER LOADING MODULE (120 mm x 56 mm)      | [M4]  |
       |       |  [ Sealed / Flared Port / Slit / PR ]       |       |
       |       +---------------------------------------------+       |
       |  (8) [M4 Insert]                       (9) [M4 Insert]      |
       |                 CABINET BOTTOM (230 mm Height)              |
       +-------------------------------------------------------------+
```

### 3.1 Split Frame Gasket Sealing Technique

To achieve **zero inter-chamber cross-leakage and zero atmospheric leakage** under high acoustic sound pressure ($> 105\text{ dB SPL}$):

```
       INTER-MODULE SEAM GASKET DETAIL (SAGITTAL CUTAWAY)

       Front Outer Face
       +--------------------+      +--------------------+
       | UPPER DRIVER PLATE |      | LOWER PORT PLATE   |
       | (12.0mm Birch/Alum)|      | (12.0mm Birch/Alum)|
       +---------+----------+      +----------+---------+
                 |                            |
                 v                            v
       +------------------------------------------------+
       | 1.5mm CLOSED-CELL EVA COMPRESSION GASKET SHEET |  <-- Continuous Hermetic Seal
       +------------------------------------------------+
                 |                            |
                 v                            v
       +--------------------+======+--------------------+
       | UPPER LANDING RIM  | SEAM | LOWER LANDING RIM  |
       | (10mm Wide Ledge)  | BAR  | (10mm Wide Ledge)  |
       +--------------------+======+--------------------+
         Cabinet Master Frame (12mm Structural Divider)
```

1. **Continuous Master Perimeter Gasket**:
   - Apply a continuous strip of $1.5\text{ mm} \times 10\text{ mm}$ closed-cell high-density EVA foam tape around the upper outer rim and lower outer rim.
2. **Inter-Module Seam Gasket Bar (T-Junction Sealing)**:
   - Apply a full-width $1.5\text{ mm} \times 10\text{ mm} \times 120\text{ mm}$ EVA gasket strip directly onto the $12.0\text{ mm}$ central divider bar.
   - The ends of the seam bar butt tightly against the side perimeter gaskets with zero gap. Apply a microscopic dab of flexible cyanoacrylate or silicone at the T-junction corners.
3. **Independent Module Clamping**:
   - The Upper Driver Module is secured by **6x M4 screws** (screws 1, 2, 3, 4, 5, 6).
   - The Lower Loading Module is secured by **4x M4 screws** (screws 7, 8, 9, 10).
   - *Autonomous Swapping Advantage*: The builder can unscrew and swap the Lower Loading Module (e.g. going from Bass-Reflex to Passive Radiator) while the Upper Driver Module remains under full torque, **preserving 100% of the upper driver gasket's airtight seal**.

---

## 4. Sub-Baffle Family Specifications (Upper & Lower Modules)

### 4.1 Upper Driver Module Specifications ($120\text{ mm} \times 116\text{ mm}$)

All upper driver plates share the identical outer rectangle of $120.0\text{ mm} \times 116.0\text{ mm} \times 12.0\text{ mm}$ with 6x perimeter $\varnothing 4.5\text{ mm}$ clearance holes (countersunk for M4 button head screws).

| Plate ID | Driver Class | Example Transducers | Through Cutout ($D_{cut}$) | Flush Rebate ($D_{reb}$) | Rebate Depth ($T_{reb}$) | Screw PCD | Fasteners |
| :--- | :--- | :--- | :---: | :---: | :---: | :---: | :---: |
| **DRV-20** | **2.0-Inch** Micro Full-Range | Peerless PLS-P830983, Dayton DMA45 | **$48.0\text{ mm}$** | $58.0\text{ mm}$ | $3.0\text{ mm}$ | $\varnothing 53.5\text{ mm}$ | 4x M3 Inserts |
| **DRV-25** | **2.5-Inch** Wideband | Tang Band W2-800SL, Dayton ND65-4 | **$54.0\text{ mm}$** | $65.0\text{ mm}$ | $3.5\text{ mm}$ | $\varnothing 60.0\text{ mm}$ | 4x M3 Inserts |
| **DRV-30** | **3.0-Inch** Reference (Std) | Dayton ND91-4, TB W3-881, Fostex FE83 | **$76.0\text{ mm}$** | $96.0\text{ mm}$ | $4.0\text{ mm}$ | $\varnothing 86.0\text{ mm}$ | 4x M4 Inserts |
| **DRV-35** | **3.5-Inch** Audiophile | MarkAudio Alpair 5.3, Pluvia 7.2 | **$84.0\text{ mm}$** | $102.0\text{ mm}$ | $4.5\text{ mm}$ | $\varnothing 93.0\text{ mm}$ | 4x M4 Inserts |
| **DRV-40** | **4.0-Inch** High Output | Dayton RS100-4, Scan-Speak 10F | **$94.0\text{ mm}$** | $114.0\text{ mm}$ | $4.5\text{ mm}$ | $\varnothing 104.0\text{ mm}$ | 4x M4 Inserts |

> [!IMPORTANT]
> **Rear Airflow Relief**: Every upper driver plate must feature a **$45^\circ$ expanding breathing chamfer** on the rear face opening, expanding the rear aperture by $+12\text{ mm}$ to $+16\text{ mm}$ beyond the through-cutout to eliminate acoustic tunnel compression behind the driver cone.

---

### 4.2 Lower Acoustic Loading Module Specifications ($120\text{ mm} \times 56\text{ mm}$)

All lower loading plates share the standardized outer dimensions of $120.0\text{ mm} \times 56.0\text{ mm} \times 12.0\text{ mm}$ with 4x perimeter $\varnothing 4.5\text{ mm}$ clearance holes at the corners.

```
       THE 4 INTERCHANGEABLE ACOUSTIC LOADING TOPOLOGIES

   1. MODE 1: SEALED BLANK           2. MODE 2: FLARED BASS-REFLEX
   +---------------------------+     +---------------------------+
   |                           |     |          ( O )            |
   |   [ Solid 12mm Birch ]    |     |   Flared Circular Port    |
   |   [ Sealed Qtc ~0.707 ]   |     |   (Ø32mm / Ø35mm Tube)    |
   +---------------------------+     +---------------------------+

   3. MODE 3: SLIT / SLOT PORT       4. MODE 4: PASSIVE RADIATOR
   +---------------------------+     +---------------------------+
   | +-----------------------+ |     |      +-------------+      |
   | | Aerodynamic Slot Port | |     |      |  ND90-PR    |      |
   | +-----------------------+ |     |      +-------------+      |
   +---------------------------+     +---------------------------+
```

#### Detailed Loading Topology Specifications:

1. **Mode 1: Sealed Acoustic Suspension Plate (`LOAD-SEAL`)**:
   - **Structure**: Solid $12\text{ mm}$ Baltic Birch, 6061 Aluminum, or dense 3D printed PETG-CF blank plate.
   - **Acoustic Characteristics**: Completely hermetic enclosure; clean second-order $12\text{ dB/octave}$ roll-off; maximum transient speed and group delay $< 2\text{ ms}$; optimal for Fostex FE83NV2 or high-$Q_{ts}$ 2" full-range drivers.
   - **Internal Damping**: Increase loose wool filling to **$65\text{ g}$** to achieve maximum isothermal air compliance.

2. **Mode 2: Front-Firing Flared Bass-Reflex Port Plate (`LOAD-PORT`)**:
   - **Structure**: Precision cutout with internal $3\text{D}$ printed dual-flared port tube ($\varnothing 32.0\text{ mm}\text{ ID} \times 138.0\text{ mm}\text{ Length}$ for $F_b = 62.0\text{ Hz}$, or $\varnothing 35.0\text{ mm}\text{ ID} \times 105.0\text{ mm}\text{ Length}$ for $F_b = 75.0\text{ Hz}$).
   - **Acoustic Characteristics**: Classic 4th-order reflex alignment; extends bass response down to $56\text{ Hz}$ ($F_3$) with high efficiency; front-firing location eliminates wall-boundary interference when placed close to back walls.

3. **Mode 3: Aerodynamic Slit / Slot Port Plate (`LOAD-SLIT`)**:
   - **Structure**: Horizontal slot vent ($90.0\text{ mm}\text{ Width} \times 12.0\text{ mm}\text{ Height} \times 125.0\text{ mm}\text{ Duct Length}$) with $R = 6.0\text{ mm}$ fully radiused mouth lips.
   - **Acoustic Characteristics**: Distributed laminar boundary airflow; highly resistant to high-volume organ-pipe whistling; sleek studio-monitor aesthetic.

4. **Mode 4: Tuned Passive Radiator Plate (`LOAD-PR`)**:
   - **Structure**: Cutout ($\varnothing 76.0\text{ mm}$ through, $\varnothing 96.0\text{ mm} \times 4.0\text{ mm}$ rebate, 4x M4 inserts on $\varnothing 86.0\text{ mm}$ PCD) mounting a **Dayton Audio ND90-PR** or **SD115-PR** passive radiator.
   - **Acoustic Characteristics**: Provides the low bass extension of a vented box with **zero port turbulence, zero air chuffing, and zero midrange leakage** through the port tube.
   - **Mass Tuning**: Add 5g to 15g brass washer weights to the PR center post to fine-tune $F_b$ between **$52\text{ Hz}$ and $65\text{ Hz}$**.

---

## 5. Quick-Disconnect Wiring Harness & Zero-Solder Platform

```
+-----------------------------------------------------------------------------------------------+
|                       ZERO-SOLDER QUICK-DISCONNECT HARNESS TOPOLOGY                           |
|                                                                                               |
|   +---------------------------------------------------------------------------------------+   |
|   | REAR PANEL BINDING POSTS (Gold-Plated 5-Way Chassis Terminals)                        |   |
|   +---------------------------------------------------------------------------------------+   |
|                                |                                                              |
|                                | 16 AWG High-Purity OFC Wire (180 mm) in Acoustic Foam Sleeve |
|                                v                                                              |
|   +---------------------------------------------------------------------------------------+   |
|   | POLARIZED INLINE CONNECTOR (Amass XT30U Gold 30A Polarized Quick-Release)              |   |
|   | Pin 1 (+): Red Lead  |  Pin 2 (-): Black Lead                                         |   |
|   +---------------------------------------------------------------------------------------+   |
|                                |                                                              |
|                                | Driver Pigtail Harness (100 mm Ultra-Flex Silicone OFC)      |
|                                v                                                              |
|   +---------------------------------------------------------------------------------------+   |
|   | PRE-TERMINATED DRIVER FASTON DISCONNECTS                                              |   |
|   | (+) Red 0.205" (5.2mm) Gold Spade  ====> Driver Positive Terminal Tag                 |   |
|   | (-) Black 0.110" (2.8mm) Gold Spade ====> Driver Negative Terminal Tag                |   |
|   +---------------------------------------------------------------------------------------+   |
+-----------------------------------------------------------------------------------------------+
```

---

## 6. Fabrication, Machining & 3D Printing Guide

### 6.1 Woodworking & Machining of Master Split Frame

```mermaid
graph TD
    A[Cut Front Baffle Blank 136x230x12mm] --> B[Plunge-Rout Master Perimeter Rebate 120x180x4mm]
    B --> C[Cut Upper Through-Window 100x100mm]
    C --> D[Leave 12mm Center Divider Bar]
    D --> E[Cut Lower Through-Window 100x40mm]
    E --> F[Drill 10x M4 Insert Holes 5.8mm on 10mm Ledge]
    F --> G[Seat M4 Brass Knurled Inserts with Epoxy]
    G --> H[Apply Perimeter & Seam EVA Gaskets]
```

1. **Outer Dimensions & Rebating**:
   - Cut front baffle blank to $136.0\text{ mm} \times 230.0\text{ mm} \times 12.0\text{ mm}$.
   - Using a plunge router with a straight mortising bit and edge guide, rout a continuous **$4.0\text{ mm}$ deep rebate** to establish the $120.0\text{ mm} \times 180.0\text{ mm}$ outer socket.
2. **Window Apertures & Divider Bar**:
   - Rout the upper through-window to $100.0\text{ mm} (\text{W}) \times 100.0\text{ mm} (\text{H})$.
   - Leave a solid **$12.0\text{ mm}$ wide structural divider bar** across the horizontal centerline.
   - Rout the lower through-window to $100.0\text{ mm} (\text{W}) \times 40.0\text{ mm} (\text{H})$.
   - This leaves a uniform **$10.0\text{ mm}$ wide landing ledge** around all perimeters for gasket seating and M4 insert placement.
3. **M4 Brass Insert Installation**:
   - Drill 10 pilot holes of **$\varnothing 5.8\text{ mm}$** into the landing ledge ($11.0\text{ mm}$ deep):
     * 6 holes around the upper window (4 corners + 2 sides).
     * 4 holes around the lower window (4 corners).
   - Coat insert threads with 5-minute epoxy and seat them $0.2\text{ mm}$ sub-flush using a hex driver.

---

### 6.2 3D Printing Guide for Sub-Baffle Modules

For rapid digital fabrication, sub-baffle plates and port adapters can be 3D printed:

```
       +------------------------------------------------------------+
       |         FDM SLICER PROFILE FOR SPLIT SUB-BAFFLE PLATES     |
       |                                                            |
       |   Filament Material    : Carbon-Fiber PETG (PETG-CF) / ABS |
       |   Nozzle Diameter      : 0.4 mm or 0.6 mm                  |
       |   Wall Perimeters      : 8 to 10 walls (>= 3.6 mm solid)   |
       |   Top / Bottom Layers  : 8 solid layers (>= 2.4 mm solid)  |
       |   Infill Pattern       : GYROID (Acoustic Resonance Trap)  |
       |   Infill Density       : 50% - 60%                         |
       |   Threaded Inserts     : Heat-Set Brass M3/M4 (235°C Iron) |
       +------------------------------------------------------------+
```

---

## 7. Step-by-Step Assembly & Independent Hot-Swap Procedure

```mermaid
sequenceDiagram
    participant U as User / Audio Engineer
    participant D as Upper Driver Module
    participant P as Lower Loading Module
    participant H as XT30 Wiring Harness
    participant E as Master Cabinet Frame

    Note over U,E: SCENARIO: Swapping Lower Loading from Reflex to Passive Radiator
    U->>P: 1. Loosen 4x M4 Screws on Lower Module (Screws 7, 8, 9, 10)
    Note over D,E: Upper Driver Module remains 100% sealed & torqued
    U->>P: 2. Remove Lower Port Plate
    U->>E: 3. Verify Seam Gasket Bar Integrity
    U->>P: 4. Insert New Passive Radiator Plate (LOAD-PR)
    U->>P: 5. Hand-thread 4x M4 Button Head Screws
    U->>P: 6. Torque Screws in Cross-Pattern to 1.2 N*m
    U->>E: 7. Execute Slow-Push Airtightness Test (1.2s Return)
    U->>E: 8. Run 20Hz-200Hz Frequency Sweep Sign-Off
```

### 7.1 Independent Swapping Protocols

#### Protocol A: Swapping the Upper Driver Module (Under 2 Minutes)
1. **Disassembly**:
   - Loosen the 6 M4 screws securing the Upper Driver Module (Screws 1, 2, 3, 4, 5, 6).
   - Tilt the driver plate forward and unclip the **XT30 polarized connector**.
   - *Note*: The Lower Loading Module remains fully torqued and sealed.
2. **Installation**:
   - Plug the new driver plate's pigtail into the XT30 harness.
   - Tuck wire neatly behind the internal window brace.
   - Seat the plate against the $1.5\text{ mm}$ EVA gasket and hand-start the 6 M4 screws.
   - Tighten following the **Upper 6-Point Cross Pattern** ($1.2 - 1.5\text{ N}\cdot\text{m}$):
     `[1] Top-Left -> [4] Bottom-Right -> [2] Top-Right -> [5] Bottom-Left -> [3] Mid-Right -> [6] Mid-Left`

#### Protocol B: Swapping the Lower Loading Module (Under 1 Minute)
1. **Disassembly**:
   - Loosen the 4 M4 screws securing the Lower Loading Module (Screws 7, 8, 9, 10).
   - Remove plate. (Zero electrical disconnect required).
2. **Installation**:
   - Seat new loading plate (e.g. `LOAD-SEAL`, `LOAD-PORT`, `LOAD-SLIT`, or `LOAD-PR`).
   - Hand-start all 4 M4 screws.
   - Tighten following the **Lower 4-Point Cross Pattern** ($1.2 - 1.5\text{ N}\cdot\text{m}$):
     `[7] Top-Left -> [9] Bottom-Right -> [10] Top-Right -> [8] Bottom-Left`

---

## 8. Quality Control, Airtightness & Acoustic Verification Checklist

Prior to acoustic testing or critical listening after any driver or port module swap:

```
                  POST-SWAP 4-STEP VERIFICATION MATRIX

    +-------------------+      +-------------------+      +-------------------+
    | 1. POLARITY CHECK |      | 2. SLOW-PUSH TEST |      | 3. SINE SWEEP QC  |
    | DC 1.5V Battery   | ===> | Depress cone 3mm  | ===> | 20 Hz - 200 Hz    |
    | Forward Excursion |      | Rebound >= 1.0s   |      | Zero Buzz/Chuff   |
    +-------------------+      +-------------------+      +-------------------+
```

### 8.1 Verification Pass / Fail Standards

| Test | Procedure | Target Pass Standard | Corrective Action if Failed |
| :--- | :--- | :--- | :--- |
| **Polarity Pop Test** | Momentarily connect 1.5V DC to binding posts | Driver cone displaces smoothly **FORWARD** | Reverse Faston spades at driver terminal |
| **Pneumatic Slow-Push**| Gently depress cone 3mm and release | Cone recovers smoothly over **$1.0\text{ s} - 1.5\text{ s}$** | Re-torque seam screws; check EVA gasket seam |
| **Acoustic Sweep** | 20 Hz – 200 Hz sine sweep at 1W RMS | Clean tone reproduction, zero rattles | Secure loose internal wire; clear port intake |
| **Seam Leak Detection**| Run 40 Hz tone at 3W; inspect seam bar with hand | **Zero air puffing** felt at inter-module seam | Tighten seam screws (4, 5, 7, 10) by 1/4 turn |

---

## 9. Master Sign-Off Checklist

- [ ] **Master Frame**: 10x M4 brass inserts installed flush and verified perpendicular.
- [ ] **Inter-Module Seam Gasket**: Full-width $1.5\text{ mm}$ EVA seam bar seated with zero corner gaps.
- [ ] **Driver Module**: Rear $45^\circ$ airflow chamfer verified on chosen driver plate.
- [ ] **Wiring Harness**: 16 AWG OFC wire sheathed in foam; XT30 connector securely keyed.
- [ ] **Loading Module**: Selected loading plate (`LOAD-SEAL`, `LOAD-PORT`, `LOAD-SLIT`, or `LOAD-PR`) seated and sealed.
- [ ] **Anti-Strip Torquing**: All M4 button head screws torqued in cross-pattern to $1.2 - 1.5\text{ N}\cdot\text{m}$.
- [ ] **Pneumatic Hermetic Seal**: Passed slow cone recovery test ($\ge 1.0\text{ s}$).
- [ ] **Polarity**: Confirmed positive outward cone excursion under DC positive voltage.
- [ ] **Acoustic Sign-Off**: 20 Hz – 500 Hz sweep completed with zero chuffing or mechanical resonance.

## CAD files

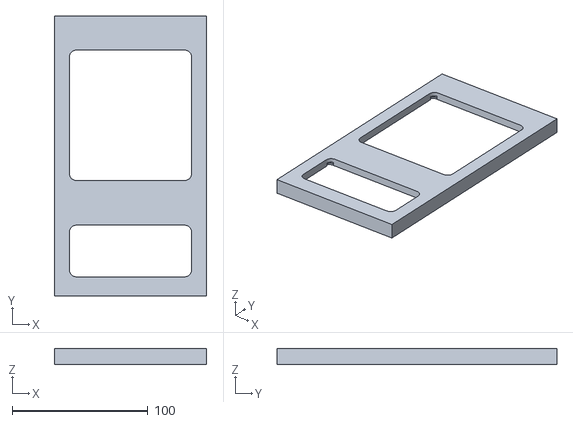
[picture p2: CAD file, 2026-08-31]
cad/stl/inset_split_main_front_baffle.stl
112.0 x 206.0 x 12.0

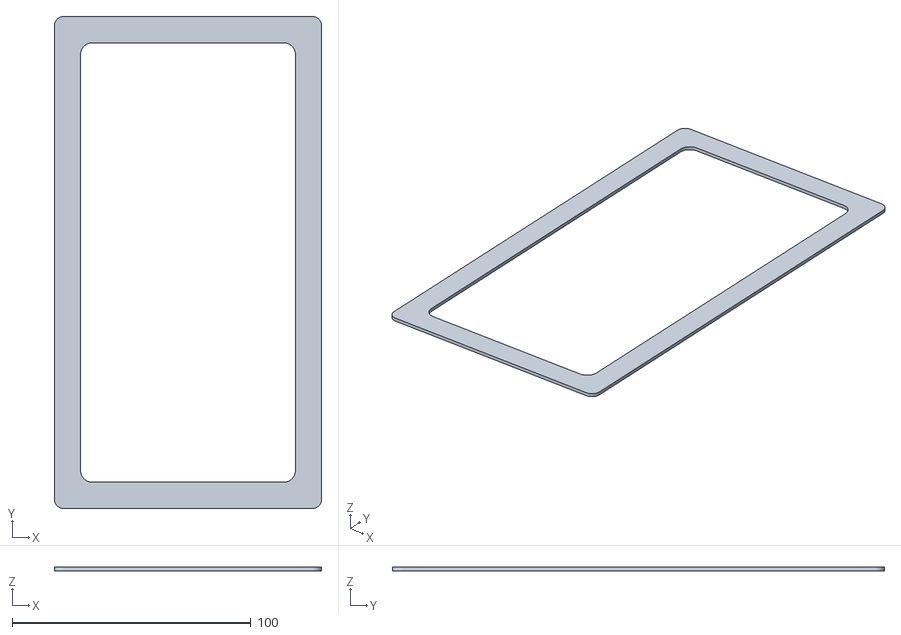
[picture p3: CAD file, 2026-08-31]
cad/stl/full_opening_gasket_eva.stl
112.0 x 206.0 x 1.50

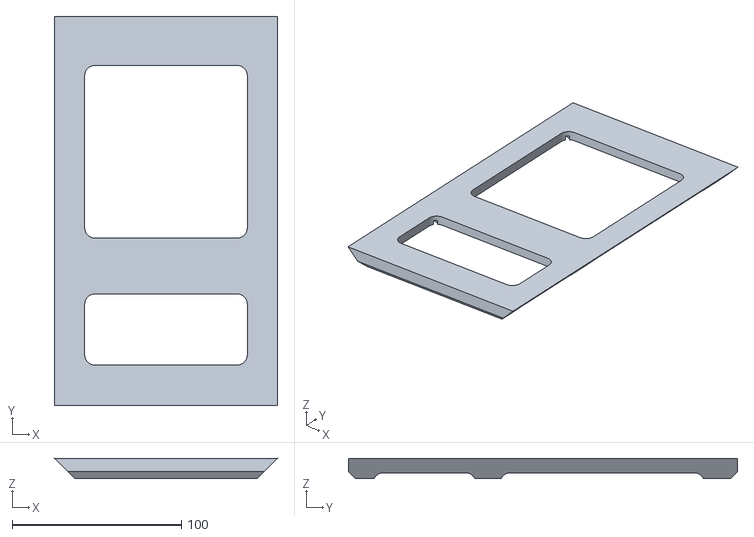
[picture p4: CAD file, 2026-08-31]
cad/stl/split_main_front_baffle.stl
131.7 x 230.0 x 12.0

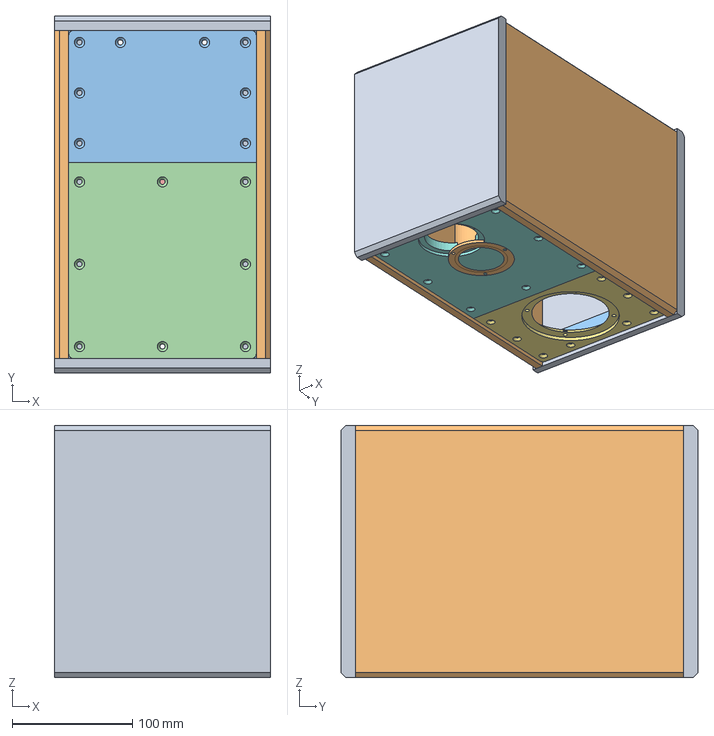
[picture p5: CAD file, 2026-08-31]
cad/speaker_enclosure_5.5L.step
180.0 x 297.0 x 210.0 mm

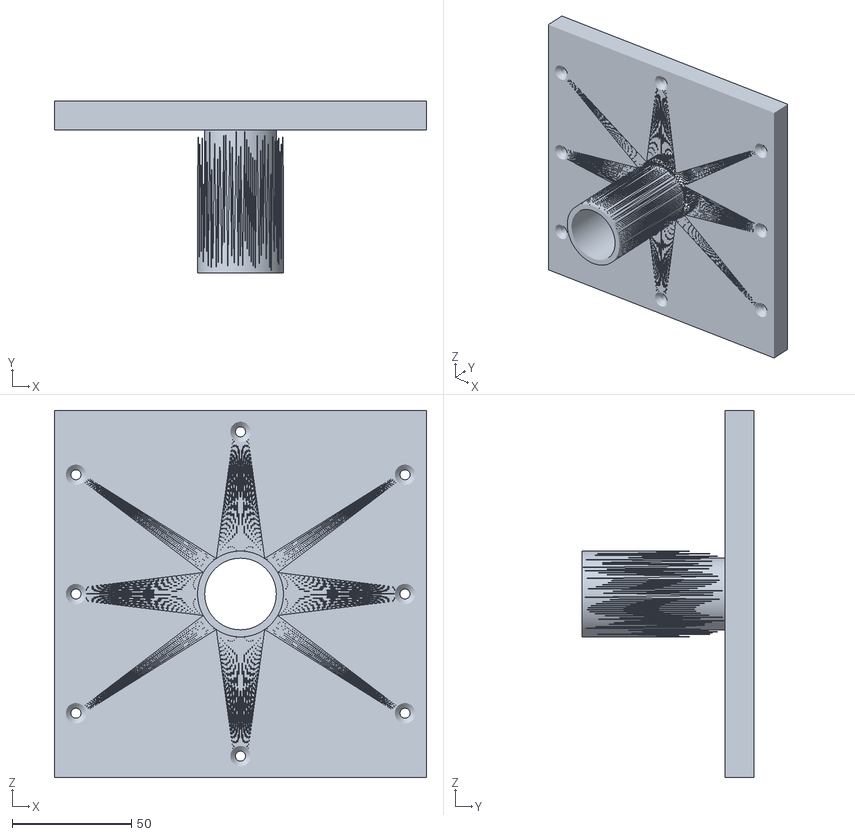
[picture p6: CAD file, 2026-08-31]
cad/stl/5.5L/removable_port_plate_2.stl
156.0 x 72.0 x 154.0

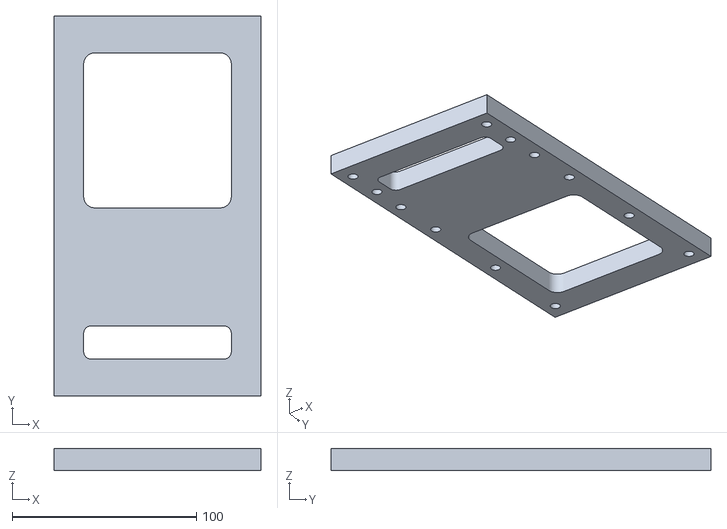
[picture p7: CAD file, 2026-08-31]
cad/stl/inner_ladder_baffle_frame.stl
112.0 x 206.0 x 12.0

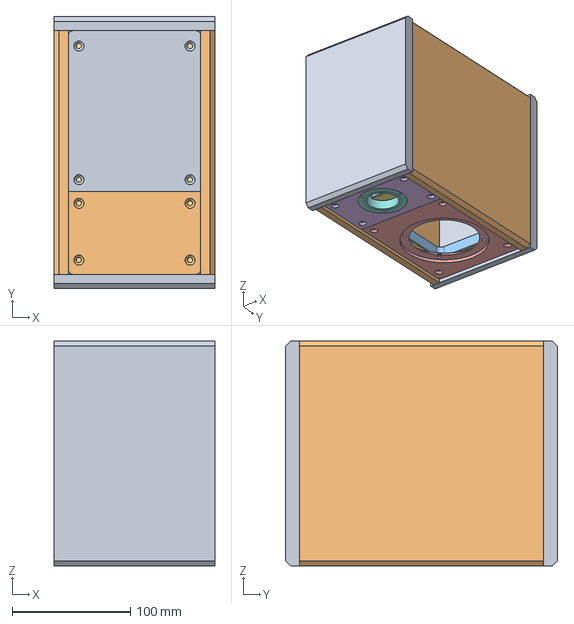
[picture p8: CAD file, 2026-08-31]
cad/speaker_enclosure.step
136.0 x 230.0 x 190.0 mm

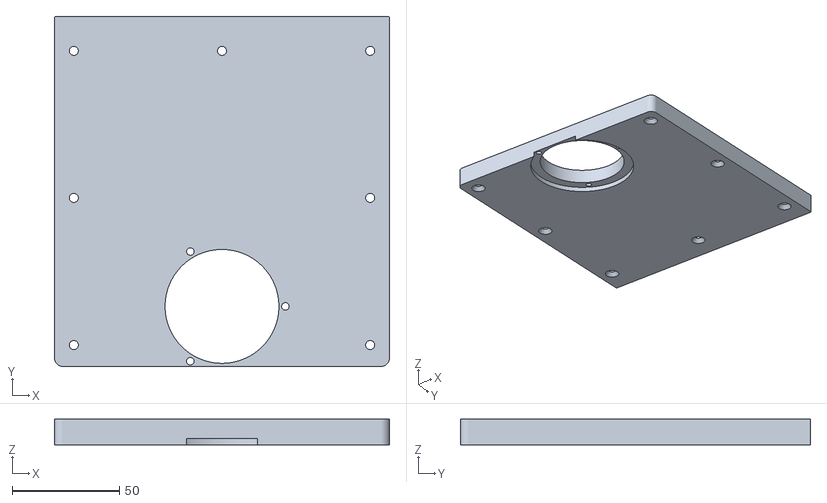
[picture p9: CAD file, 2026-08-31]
cad/stl/5.5L/lower_plate_55L_p2_port_socket.stl
156.0 x 163.0 x 12.0

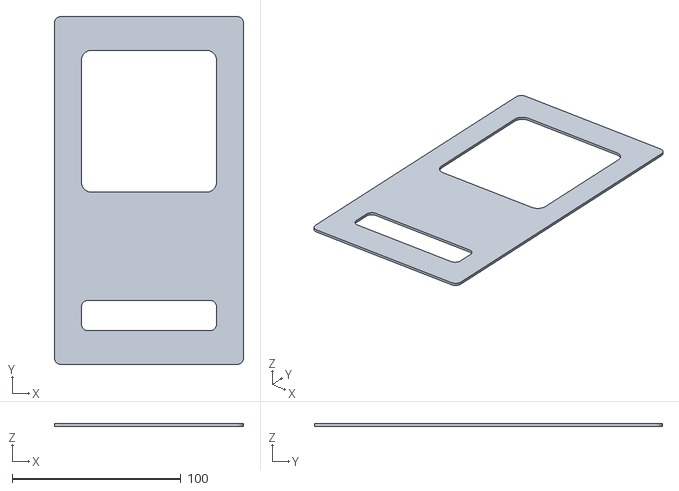
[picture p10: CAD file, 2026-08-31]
cad/stl/ladder_frame_gasket_eva.stl
112.0 x 206.0 x 1.50

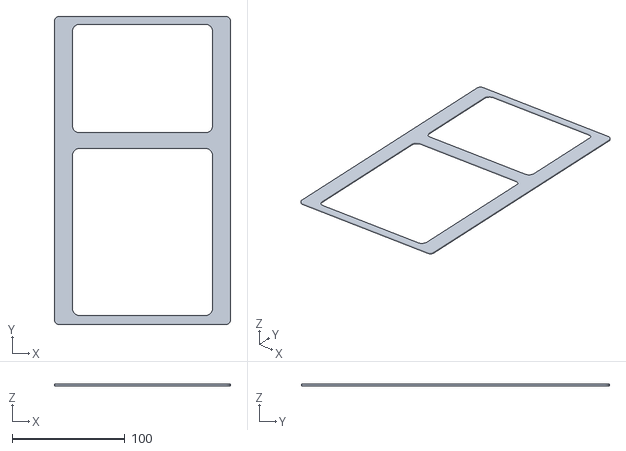
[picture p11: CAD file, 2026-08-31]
cad/stl/5.5L/ladder_frame_gasket_180mm_eva.stl
156.0 x 273.0 x 1.50

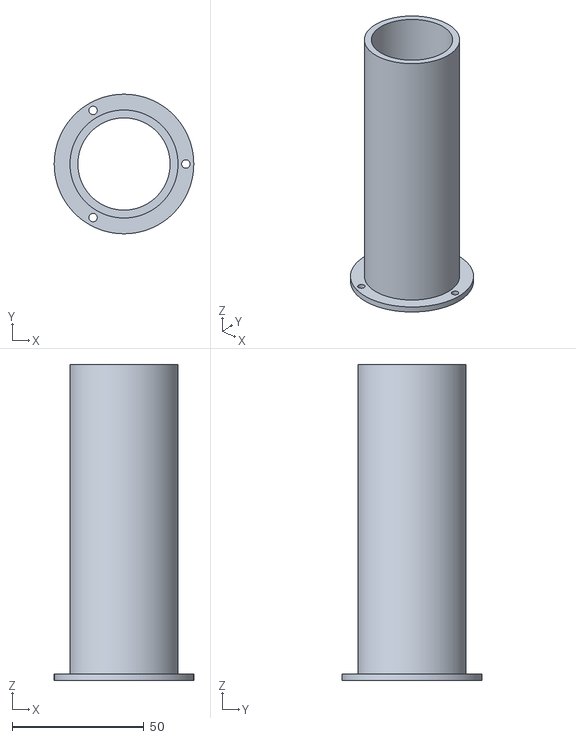
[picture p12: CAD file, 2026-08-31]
cad/stl/port_tube_120mm.stl
53.0 x 53.0 x 120.0

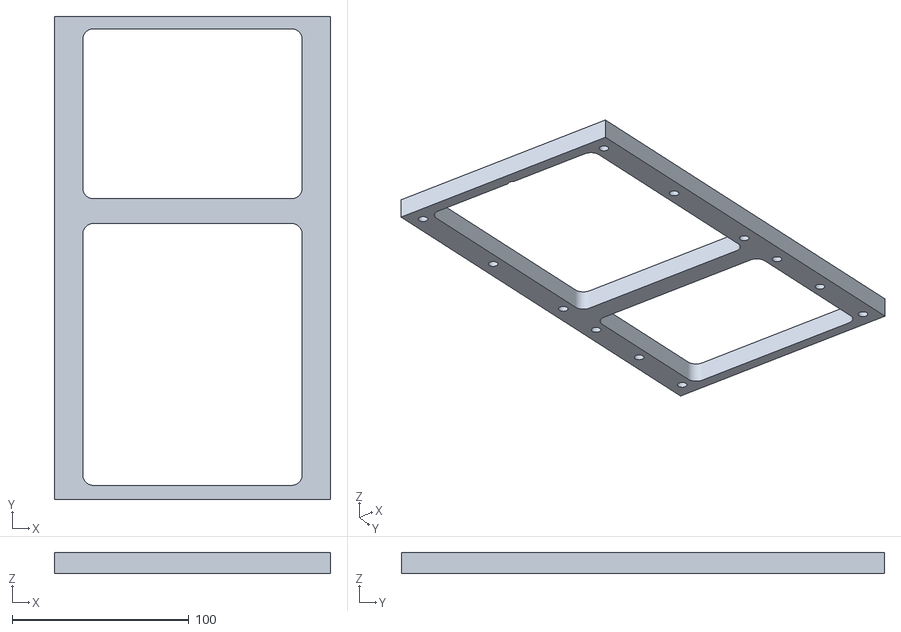
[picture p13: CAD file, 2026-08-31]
cad/stl/5.5L/inner_ladder_baffle_frame_180mm.stl
156.0 x 273.0 x 12.0

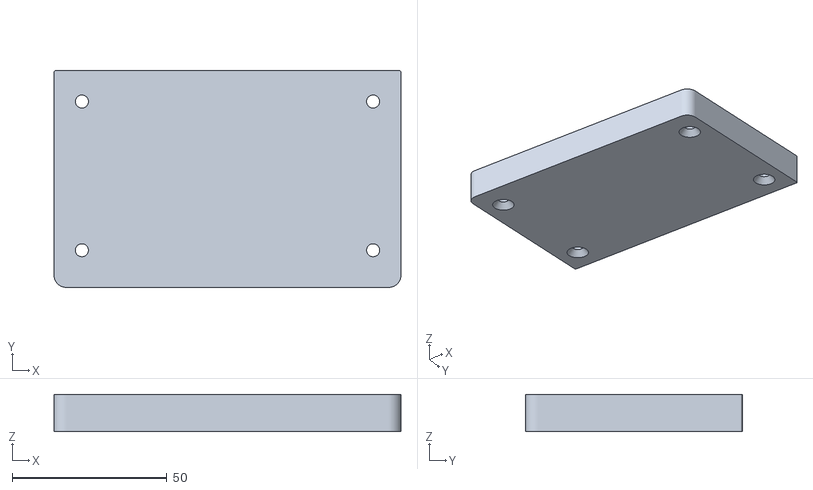
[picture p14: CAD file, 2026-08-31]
cad/stl/rear_lower_solid_plate.stl
112.0 x 70.0 x 12.0

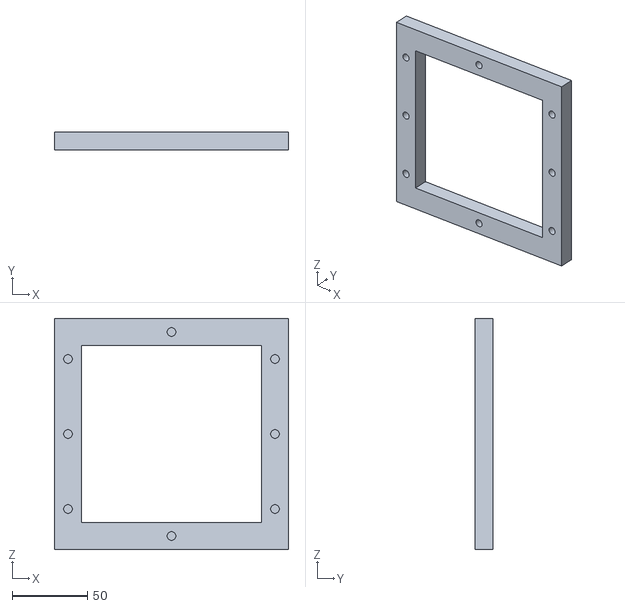
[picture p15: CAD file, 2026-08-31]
cad/stl/5.5L/mouth_partition_plate_1.stl
156.0 x 12.0 x 154.0

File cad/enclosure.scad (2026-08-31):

// =============================================================================
// SYMMETRICAL DUAL-FACE "日" LADDER FRAME SPEAKER ENCLOSURE (2" TO 4" DRIVERS)
// File: enclosure.scad
// Author: Speaker Mechanical & CAD Engineer
// Description: Symmetrical Dual-Face Modular Baffle Architecture:
//              - Front & Rear Identical "日" Inner Fixed Frames (112x206x12mm):
//                * Front Frame: Z=16..28mm (40mm crossbar at Y=62..102mm)
//                * Rear Frame:  Z=162..174mm (40mm crossbar at Y=62..102mm)
//                * Upper Window: 90.0 x 106.0 mm (Y: 102 to 208 mm, center Y=155 mm)
//                * Lower Window: 90.0 x 40.0 mm (Y: 22 to 62 mm, center Y=42 mm)
//              - Internal Window Brace: 112x12x134mm at Y=82mm (Z=28..162mm)
//                directly linking front and rear 40mm crossbars as a tie-beam.
//              - Front Baffles (Z=4..16mm): Upper U1..U4 + Lower P1..P4
//              - Rear Baffles (Z=174..186mm): Upper Solid Blank + Lower Solid Blank
//              - Symmetrical 4.0mm Inset Recesses on Front (Z=0..4) and Rear (Z=186..190)
// =============================================================================

/* [View Settings] */
// View Mode: 0=Assembled Solid, 1=Cutaway Section, 2=Exploded Assembly, 3=Transparent X-Ray, 4=2D CNC Cut Sheet
view_mode = 0; // [0:Assembled Solid, 1:Cutaway Section, 2:Exploded Assembly, 3:Transparent X-Ray, 4:2D CNC Cut Sheet]

// Explode distance multiplier (for exploded view)
explode_dist = 70; // [30:1:180]

// Cutaway axis: 0=Half X Sagittal, 1=Half Z Coronal, 2=Quarter Cut
cutaway_type = 0; // [0:Half X Sagittal, 1:Half Z Coronal, 2:Quarter Cut]

/* [Upper Module - Driver Section] */
// Active Front Driver Sub-Baffle Plate (12.0mm Thick):
// 1=Plate U1 (2-2.5" Drivers: Ø56mm cutout, Ø68mm rebate, PCD Ø62mm)
// 2=Plate U2 (3-3.5" Benchmark Drivers: Ø76mm cutout, Ø96mm rebate, PCD Ø86mm)
// 3=Plate U3 (3.5-4" Woofers: Ø96mm cutout, Ø108mm rebate, PCD Ø104mm)
// 4=Plate U4 (Blank Solid Driver Plate)
upper_module_plate = 2; // [1:Plate U1 (2-2.5 Inch), 2:Plate U2 (3-3.5 Inch Benchmark), 3:Plate U3 (3.5-4 Inch Woofer), 4:Plate U4 (Blank Plate)]

/* [Lower Module - Acoustic Alignment Section] */
// Active Front Lower Acoustic Alignment Module (12.0mm Thick):
// 1=Module P1: Sealed Plate (Solid blank for Acoustic Suspension)
// 2=Module P2: Front Bass-Reflex Port Plate (Holds interchangeable cylindrical tubes: 80mm/120mm/150mm)
// 3=Module P3: Slit Duct Port Plate (Integrated horizontal front slit port)
// 4=Module P4: Passive Radiator Mount Plate (3-4" passive radiator cutout)
lower_module_mode = 2; // [1:Module P1 (Sealed Acoustic Suspension), 2:Module P2 (Front Cylindrical Flared Port), 3:Module P3 (Slit Duct Port), 4:Module P4 (Passive Radiator)]

// Cylindrical port length for Module P2 (80mm, 120mm, 150mm)
p2_port_len = 120.0; // [80.0:Short (85Hz), 120.0:Standard (71Hz), 150.0:Long (65Hz)]

/* [Cabinet Core Dimensions (mm)] */
panel_t           = 12.0;  // Cabinet wall thickness (12mm Baltic Birch / MDF)
outer_w           = 136.0; // Outer cabinet width
outer_h           = 230.0; // Outer cabinet height
outer_d           = 190.0; // Outer cabinet depth

baffle_recess     = 4.0;   // Symmetrical recess depth on front and rear (mm)

/* [Heavy-Duty Dual-Layer Dimensions (mm)] */
swap_plate_t      = 12.0;  // Swappable baffle thickness (12mm)
frame_t           = 12.0;  // Inner fixed frame thickness (12mm)
total_baffle_t    = 24.0;  // 12mm swap + 12mm frame = 24mm clamping rim
gasket_t          = 1.5;   // Compressed gasket thickness (mm)

// "日" Wide 40mm Ladder Frame Dimensions (mm)
upper_win_w       = 90.0;
upper_win_h       = 106.0;
upper_win_y       = 155.0; // Center Y of upper window (spans Y=102..208)
crossbar_h        = 40.0;  // Height of crossbar (spans Y=62..102, center Y=82)
lower_win_w       = 90.0;
lower_win_h       = 40.0;
lower_win_y       = 42.0;  // Center Y of lower window (spans Y=22..62)

// Upper Driver Plate (112 x 136 x 12mm)
upper_plate_w     = 112.0;
upper_plate_h     = 136.0;
upper_pos_y       = 150.0; // Spans Y=82 to Y=218 (Center Y=150.0)
driver_pos_y      = 155.0; // Acoustic center of driver

// Lower Acoustic Plate (112 x 70 x 12mm)
lower_plate_w     = 112.0;
lower_plate_h     = 70.0;
lower_pos_y       = 47.0;  // Spans Y=12 to Y=82 (Center Y=47.0)
acoustic_pos_y    = 47.0;  // Acoustic center

split_joint_y     = 82.0;  // Horizontal split line (Center of Crossbar)

fastener_d        = 4.2;   // M4 countersunk screw clearance hole

/* [Internal Bracing Parameters] */
brace_enable      = true;
brace_pos_y       = 82.0;  // Aligned directly linking front and rear 40mm crossbars
brace_rim_w       = 24.0;
brace_corner_r    = 15.0;

/* [Rendering Quality] */
$fn = 64;

// =============================================================================
// DERIVED DIMENSIONS & ACOUSTIC CALCULATIONS
// =============================================================================
inner_w = outer_w - 2 * panel_t; // 112 mm
inner_h = outer_h - 2 * panel_t; // 206 mm

// Z-Coordinates:
z_front_swap_start  = baffle_recess;                               // 4.0 mm
z_front_swap_end    = baffle_recess + swap_plate_t;                // 16.0 mm
z_front_frame_start = z_front_swap_end;                            // 16.0 mm
z_front_frame_end   = z_front_swap_end + frame_t;                  // 28.0 mm

z_cavity_start      = z_front_frame_end;                           // 28.0 mm
z_cavity_end        = outer_d - baffle_recess - swap_plate_t - frame_t; // 162.0 mm
inner_d             = z_cavity_end - z_cavity_start;               // 134.0 mm

z_rear_frame_start  = z_cavity_end;                                // 162.0 mm
z_rear_frame_end    = z_rear_frame_start + frame_t;                // 174.0 mm
z_rear_swap_start   = z_rear_frame_end;                            // 174.0 mm
z_rear_swap_end     = z_rear_swap_start + swap_plate_t;            // 186.0 mm

v_gross_liters = ((inner_w * inner_h * inner_d) + 2 * (upper_win_w * upper_win_h * frame_t + lower_win_w * lower_win_h * frame_t)) / 1000000; // ~3.406 L

v_driver_liters = (upper_module_plate == 1) ? 0.100 :
                  (upper_module_plate == 2) ? 0.180 :
                  (upper_module_plate == 3) ? 0.260 : 0.050;

v_lower_liters  = (lower_module_mode == 1) ? 0.000 :
                  (lower_module_mode == 2) ? (PI * pow((35/2 + 3), 2) * (p2_port_len - swap_plate_t)) / 1000000 :
                  (lower_module_mode == 3) ? (90 * 18 * 120) / 1000000 : 0.060;

v_brace_liters  = ((inner_w * inner_d) - ((inner_w - 2*brace_rim_w) * (inner_d - 2*brace_rim_w) - 4*pow(brace_corner_r, 2) + PI*pow(brace_corner_r, 2))) * panel_t / 1000000; // ~0.100 L
v_net_liters    = v_gross_liters - (v_driver_liters + v_lower_liters + v_brace_liters);
v_effective     = v_net_liters * 1.08;

// Acoustic Tuning Calculation
speed_sound     = 343000; // mm/s
port_area_mm2   = (lower_module_mode == 2) ? PI * pow(35 / 2, 2) :
                  (lower_module_mode == 3) ? (90 * 14) : 0;
port_eff_len_mm = (lower_module_mode == 2) ? (p2_port_len + 1.7 * (35 / 2)) :
                  (lower_module_mode == 3) ? (120.0 + 0.85 * sqrt(1260 / PI)) : 1;
tuning_freq_hz  = (port_area_mm2 > 0) ? (speed_sound / (2 * PI)) * sqrt(port_area_mm2 / ((v_net_liters * 1000000) * port_eff_len_mm)) : 0;

echo("=================================================================");
echo(str("SYMMETRICAL DUAL-FACE '日' LADDER FRAME SYSTEM:"));
echo(str("Gross Enclosure Volume: ", v_gross_liters, " L"));
echo(str("Net Enclosure Volume:   ", v_net_liters, " L"));
echo(str("Effective Damped Vol:   ", v_effective, " L"));
echo(str("Internal Cavity Depth:  ", inner_d, " mm (Z=28 to 162mm)"));
echo(str("Front & Rear Frames:    Z=16..28mm & Z=162..174mm (40mm Crossbars)"));
if (lower_module_mode == 1) {
    echo("Acoustic Alignment:     Sealed (Acoustic Suspension, Qtc ~ 0.70)");
} else if (lower_module_mode == 2 || lower_module_mode == 3) {
    echo(str("Tuning Frequency (Fb):  ", tuning_freq_hz, " Hz"));
} else if (lower_module_mode == 4) {
    echo("Acoustic Alignment:     Passive Radiator (Fb ~ 58-65 Hz)");
}
echo("=================================================================");

// =============================================================================
// COLOR PALETTE
// =============================================================================
c_wood_cabinet  = [0.80, 0.66, 0.48, 1.0];
c_wood_baffle   = [0.86, 0.72, 0.54, 1.0];
c_brace         = [0.72, 0.56, 0.38, 1.0];
c_plate_u1      = [0.20, 0.65, 0.85, 1.0];
c_plate_u2      = [0.85, 0.75, 0.20, 1.0];
c_plate_u3      = [0.85, 0.30, 0.25, 1.0];
c_plate_u4      = [0.45, 0.45, 0.50, 1.0];
c_plate_p1      = [0.35, 0.40, 0.48, 1.0];
c_plate_p2      = [0.10, 0.55, 0.80, 1.0];
c_plate_p3      = [0.15, 0.70, 0.45, 1.0];
c_plate_p4      = [0.75, 0.40, 0.80, 1.0];
c_gasket        = [0.15, 0.15, 0.15, 1.0];
c_xray          = [0.82, 0.72, 0.58, 0.35];
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

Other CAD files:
cad/stl/port_tube_150mm.stl
cad/stl/5.5L/upper_plate_u4_blank.stl
cad/stl/upper_plate_u2_3inch.stl
cad/stl/5.5L/upper_plate_u3_4inch.stl
cad/speaker_enclosure.FCStd
cad/speaker_enclosure_5.5L.FCStd
cad/stl/5.5L/inner_ladder_baffle_frame_55L.stl
cad/stl/5.5L/internal_dbr_partition_brace.stl
cad/stl/5.5L/internal_hollow_mouth_frame.stl
cad/stl/5.5L/ladder_frame_gasket_55L_eva.stl
cad/stl/5.5L/lower_plate_55L_p1_sealed.stl
cad/stl/5.5L/lower_plate_55L_p3_slit_port.stl
cad/stl/5.5L/lower_plate_55L_p4_passive_rad.stl
cad/stl/5.5L/port_tube_45mm_120mm.stl
cad/stl/5.5L/rear_lower_solid_plate_55L.stl
cad/stl/5.5L/rear_upper_solid_plate.stl
cad/stl/5.5L/removable_dbr_partition_plate.stl
cad/stl/5.5L/upper_plate_u1_2inch.stl
cad/stl/5.5L/upper_plate_u2_3inch.stl
cad/stl/inner_fixed_baffle_frame.stl
cad/stl/inner_front_baffle_frame.stl
cad/stl/inset_rear_panel.stl
cad/stl/lower_gasket_eva.stl
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

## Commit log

2026-08-31 feat: complete modular speaker enclosure design (3.2L compact & 5.5L DBR models)
    [enclosure.scad, full_opening_gasket_eva.stl, inner_fixed_baffle_frame.stl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]
2026-08-31 fix(cad): expand center crossbar to 56mm (28mm margins) and 14mm flanges for easy, unhindered baffle screw fastening
    [inner_ladder_baffle_frame.stl, inner_ladder_baffle_frame_55L.stl, ladder_frame_gasket_55L_eva.stl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]
2026-08-31 fix(cad): resolve 5.5L coordinate offset bug and expand center crossbar to 64mm (32mm symmetric margins) for unhindered screw fastening
    [inner_ladder_baffle_frame.stl, inner_ladder_baffle_frame_55L.stl, ladder_frame_gasket_55L_eva.stl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]
2026-08-31 fix(cad): maximize center crossbar to 80mm ultra-heavy-duty bar (40mm margins) for massive, unhindered screw fastening
    [inner_ladder_baffle_frame.stl, inner_ladder_baffle_frame_55L.stl, ladder_frame_gasket_55L_eva.stl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]
2026-08-31 fix(cad): perfectly center screws at X=+-47mm on 18mm wide solid side flanges and 80mm crossbar
    [inner_ladder_baffle_frame.stl, inner_ladder_baffle_frame_55L.stl, ladder_frame_gasket_55L_eva.stl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]
2026-08-31 feat(viewer): fully visualize 8x brass insert nut threaded sockets on sub-baffle frame
2026-08-31 fix(geometry): eliminate coordinate offset, fully sync sub-baffle crossbar Y=122..202mm with internal partition and X=+-47mm screws
    [speaker_enclosure.FCStd, speaker_enclosure.step, speaker_enclosure_5.5L.FCStd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]
2026-08-31 fix(cad): expand top/bottom flanges to 24mm (Y=286/24mm nuts) ensuring 100% solid wood backup for all 8 bolts
    [inner_ladder_baffle_frame_55L.stl, ladder_frame_gasket_55L_eva.stl, speaker_enclosure_5.5L.FCStd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]
2026-08-31 feat(viewer): drill 8x real cylindrical holes into sub-baffle geometry and add 1-click sub-baffle inspection mode
2026-08-31 feat(viewer): launch viewer in default Explode mode to immediately display sub-baffle brass threaded insert nuts
    [speaker_enclosure_5.5L.FCStd, speaker_enclosure_5.5L.step]
2026-08-31 feat(cad): apply golden-ratio sub-baffle geometry (80mm width, 64mm crossbar, 16mm side flanges) for +23% acoustic airflow and rock-solid fastening
    [inner_ladder_baffle_frame.stl, inner_ladder_baffle_frame_55L.stl, ladder_frame_gasket_55L_eva.stl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]
2026-08-31 feat(cad): upgrade baffle fastening to 12-bolt ultra-rigid pattern (6 screws per plate) with 55-62mm span for zero resonance and ironclad sealing
    [inner_ladder_baffle_frame.stl, inner_ladder_baffle_frame_55L.stl, lower_plate_55L_p1_sealed.stl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]
2026-08-31 feat(cad): set enclosure side profile to exact A4 dimensions (H297 x D210 x W144mm) with 12-bolt ultra-rigid dual-chamber DBR structure
    [inner_ladder_baffle_frame_55L.stl, internal_dbr_partition_brace.stl, ladder_frame_gasket_55L_eva.stl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]
2026-08-31 feat(viewer): implement interactive DB vs single bass-reflex switch with hollow box cavity and modular partition
2026-08-31 feat(cad): expand width to 180mm with hollow mouth frame and removable DBR partition plate (V1=2.5L < V2=3.6L)
    [inner_ladder_baffle_frame_180mm.stl, internal_hollow_mouth_frame.stl, ladder_frame_gasket_180mm_eva.stl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]
2026-08-31 fix(cad): resolve geometry overlap between outer hollow frame (156x154mm) and inner removable partition plate (120x118mm)
    [removable_dbr_partition_plate.stl, speaker_enclosure_5.5L.FCStd, speaker_enclosure_5.5L.step]
2026-08-31 feat(cad): implement insertable 4-bolt removable DBR partition plate (118x105mm) fitting through lower window (120x111mm)
    [internal_hollow_mouth_frame.stl, removable_dbr_partition_plate.stl, speaker_enclosure_5.5L.FCStd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]
2026-08-31 feat(viewer): implement front-sliding cassette partition that transforms to single bass-reflex with lower port attached
2026-08-31 feat(cad): strictly implement 1. mouth partition plate (156x154mm) and 2. bottom-screwed port plate (156x154mm) for DBR transform
    [mouth_partition_plate_1.stl, removable_port_plate_2.stl, speaker_enclosure_5.5L.FCStd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]
2026-08-31 fix(viewer): add distinct black EVA gasket and synchronized downward explode separation for mouth partition (1) and bottom port plate (2)
2026-08-31 fix(viewer): reconstruct mouth partition frame as true hollow 4-bar frame with 100x98mm opening
2026-08-31 feat(cad): maximize mouth opening to 120x118mm (59% open area) and implement 8-bolt perimeter rigid fastening
    [mouth_partition_plate_1.stl, removable_port_plate_2.stl, speaker_enclosure_5.5L.FCStd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]
2026-08-31 feat(cad): add center mounting screws (8-bolt fixing per upper/lower baffle, 16 nuts per inner frame)
    [inner_ladder_baffle_frame_180mm.stl, lower_plate_55L_p1_sealed.stl, lower_plate_55L_p2_port_socket.stl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]
2026-08-31 feat(cad): verify assembly clearance and set removable port plate to 138x136mm for window pass-through
    [removable_port_plate_2.stl, speaker_enclosure_5.5L.FCStd, speaker_enclosure_5.5L.step]
2026-08-31 fix(cad): resolve port interference with staggered port layout (P1 top-right, P2 btm-left) and unit-avoiding screws
    [inner_ladder_baffle_frame_180mm.stl, lower_plate_55L_p1_sealed.stl, lower_plate_55L_p2_port_socket.stl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]
2026-08-31 feat(cad): restore identical 156x154mm outer shape for partition port plate and set symmetrical centered ports
    [inner_ladder_baffle_frame_180mm.stl, lower_plate_55L_p1_sealed.stl, lower_plate_55L_p2_port_socket.stl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]
2026-08-31 fix(cad): align partition plate center exactly with baffle split line Y=175.0mm
    [mouth_partition_plate_1.stl, removable_port_plate_2.stl, speaker_enclosure_5.5L.FCStd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]
2026-08-31 fix(cad): totally eliminate gap (red), expand sub-baffle window (yellow), and resolve port collision (green)
    [inner_ladder_baffle_frame_180mm.stl, ladder_frame_gasket_180mm_eva.stl, lower_plate_55L_p2_port_socket.stl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]
2026-08-31 fix(cad): rebuild 3D viewer with 5-bar sub-baffle assembly, flush zero-gap partition, and isolated ports
2026-08-31 fix(viewer): move center crossbar to Y=181-192mm (above partition plate) to eliminate visual gap between partition plates
2026-08-31 fix(viewer): move 2nd external port center from Y=40mm to Y=55mm to eliminate screw interference (33mm clearance from bottom center screw)
2026-08-31 fix(viewer): make sub-baffle frame match screw layouts; add screw holes to partition
2026-08-31 feat(viewer): add explicit pilot holes to sub-baffle and partition plate
2026-08-31 fix(viewer): properly render 16 insert nuts with pilot holes on sub-baffle and 8 on partition plate
2026-08-31 fix(cad): convert all insert nut pilot holes to 100% full through-holes on sub-baffle and partition
2026-08-31 fix(cad): complete through-hole treatment for both ① mouth partition and ② port plate
2026-08-31 feat(viewer): add dedicated toggle button to hide/show ② port partition plate directly
2026-08-31 fix(viewer): place sub-baffle insert nuts on the FRONT face (mating face) with through-holes to the rear
2026-08-31 feat(viewer): add dedicated button to toggle screws and insert nuts visibility
2026-08-31 feat(viewer): ensure all screw holes / pilot holes remain permanently visible even when metal screws are hidden
2026-08-31 feat(cad): add precision alignment dowel pins (φ5x16mm) for shell, sub-baffles, and mouth partition
2026-08-31 feat(viewer): add X-Ray transparency mode and full 6-axis exploded assembly view for instant dowel pin inspection
2026-08-31 fix(viewer): ensure baffle face screws toggle properly with the screws visibility button
2026-08-31 fix(viewer): cut true 3D through-holes for all 16 screws on rear upper and lower baffles
2026-08-31 feat(cad): remove alignment dowel pins to simplify DIY woodworking fabrication
